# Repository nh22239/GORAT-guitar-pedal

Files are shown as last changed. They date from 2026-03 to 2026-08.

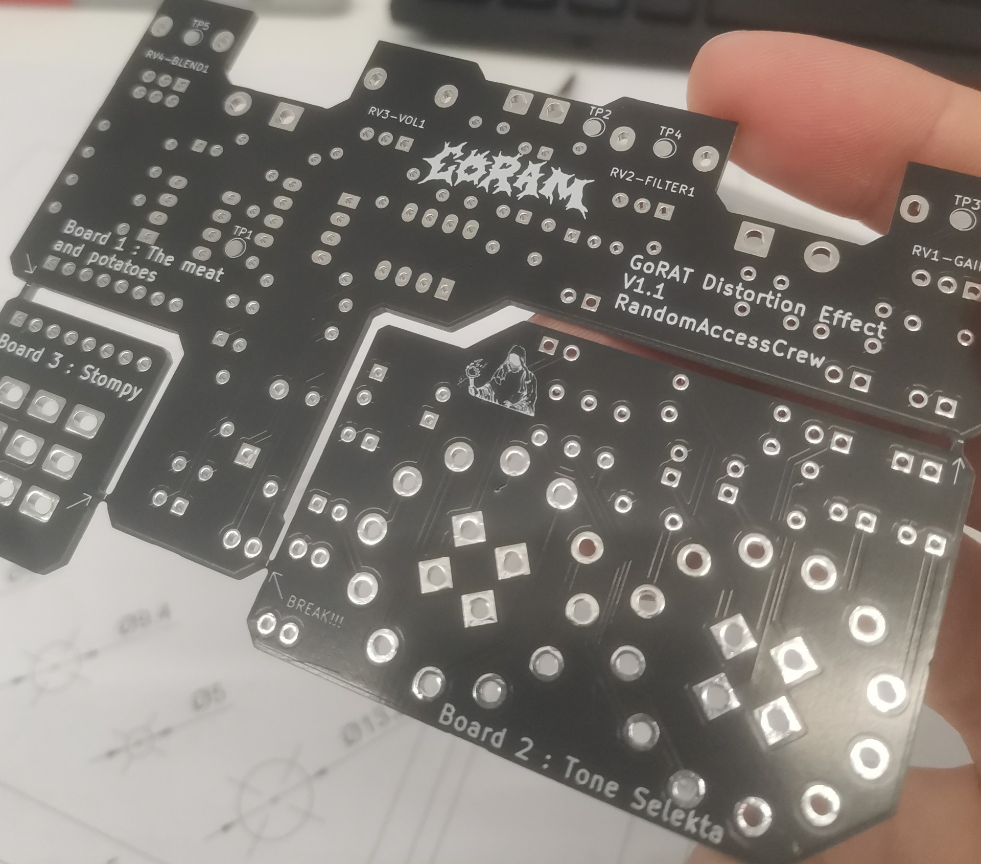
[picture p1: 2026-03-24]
PCBv1.1 delivery.jpg

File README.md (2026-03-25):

goram

# GORAT RAT clone 
Here at **GORAM** industries, we love the sound of a good dirty **RAT**, but what if we all want to use one at the same time? Suffice to say, we'd probably all get lost in eachothers sound.
That's why we've decided to go custom, a brand new **RAT** clone built by **GORAM**, for **GORAM**.

## New features:
### Frequency response selector switch!

  A simple knob that allows switching the filters of the op-amp stage between **Regular**, **Bass**, and **BEANS** modes
  
### Diode selector switch

  Pick between 6 different diode combinations
  1. BAT41 - BAT 41
  2. Red LED - Red LED 
  3. 1N914 - 1N914
  4. 1N914 - Open
  5. BAT41 - 1N914
  6. BAT41 - Red LED

### Wet/Dry knob
  Does what it says on the tin, for when the un-adulterated bass tone needs to shine through a bit more.

## Future Features:
### Diode selector gain compensation
  When switching diodes, also switch feedback resistor on a compensation op-amp.
### SMD components
  The enclosure is very busy, any new features would probably require this.
### Mini versions
  Much smaller package sizes individualised for Bass, Standard, and Beans.
### Colour LED display
  Switch between red, green, and blue when the feedback capacitor selector is changed, easy to implement as the 4x3 rotarty switch has a free pole but version 1.1 has run out of board space.

## Update 24/03/2026
The PCB's have arrived!
Due to the different heights of components, not to mention mechanical strain, I've designed the board to be printed as one piece that snaps off into three. The intention is that the breakout for the stomp button, and having flying wires for all of the jacks, will reduce the wear on the piece and contribute to a more professional finish.

PCBv1 1 delivery

LineDrawing
<?xml version="1.0" encoding="UTF-8" standalone="no"?>
<!-- Created with Inkscape (http://www.inkscape.org/) -->

<svg
   width="210mm"
   height="297mm"
   viewBox="0 0 210 297"
   version="1.1"
   id="svg1"
   xml:space="preserve"
   inkscape:version="1.4.2 (ebf0e94, 2025-05-08)"
   sodipodi:docname="LineDrawing.svg"
   xmlns:inkscape="http://www.inkscape.org/namespaces/inkscape"
   xmlns:sodipodi="http://sodipodi.sourceforge.net/DTD/sodipodi-0.dtd"
   xmlns="http://www.w3.org/2000/svg"
   xmlns:svg="http://www.w3.org/2000/svg"><sodipodi:namedview
     id="namedview1"
     pagecolor="#ffffff"
     bordercolor="#000000"
     borderopacity="0.25"
     inkscape:showpageshadow="2"
     inkscape:pageopacity="0.0"
     inkscape:pagecheckerboard="0"
     inkscape:deskcolor="#d1d1d1"
     inkscape:document-units="mm"
     inkscape:zoom="0.68862935"
     inkscape:cx="238.15424"
     inkscape:cy="382.64416"
     inkscape:window-width="1920"
     inkscape:window-height="991"
     inkscape:window-x="3191"
     inkscape:window-y="435"
     inkscape:window-maximized="1"
     inkscape:current-layer="layer1" /><defs
     id="defs1"><rect
       x="546.73824"
       y="238.45997"
       width="66.79936"
       height="36.65103"
       id="rect40" /><marker
       id="DistanceX"
       orient="auto"
       refX="0.0"
       refY="0.0"
       style="overflow:visible"><path
         d="M 3,-3 L -3,3 M 0,-5 L  0,5"
         style="stroke:#000000; stroke-width:0.5"
         id="path1" /></marker><pattern
       id="Hatch"
       patternUnits="userSpaceOnUse"
       width="8"
       height="8"
       x="0"
       y="0"><path
         d="M8 4 l-4,4"
         stroke="#000000"
         stroke-width="0.25"
         linecap="square"
         id="path2" /><path
         d="M6 2 l-4,4"
         stroke="#000000"
         stroke-width="0.25"
         linecap="square"
         id="path3" /><path
         d="M4 0 l-4,4"
         stroke="#000000"
         stroke-width="0.25"
         linecap="square"
         id="path4" /></pattern><symbol
       id="*MODEL_SPACE" /><symbol
       id="*PAPER_SPACE" /><marker
       id="DistanceX-0"
       orient="auto"
       refX="0.0"
       refY="0.0"
       style="overflow:visible"><path
         d="M 3,-3 L -3,3 M 0,-5 L  0,5"
         style="stroke:#000000; stroke-width:0.5"
         id="path1-9" /></marker><pattern
       id="Hatch-4"
       patternUnits="userSpaceOnUse"
       width="8"
       height="8"
       x="0"
       y="0"><path
         d="M8 4 l-4,4"
         stroke="#000000"
         stroke-width="0.25"
         linecap="square"
         id="path2-8" /><path
         d="M6 2 l-4,4"
         stroke="#000000"
         stroke-width="0.25"
         linecap="square"
         id="path3-8" /><path
         d="M4 0 l-4,4"
         stroke="#000000"
         stroke-width="0.25"
         linecap="square"
         id="path4-2" /></pattern><symbol
       id="*MODEL_SPACE-4" /><symbol
       id="*PAPER_SPACE-5" /><marker
       id="DistanceX-1"
       orient="auto"
       refX="0.0"
       refY="0.0"
       style="overflow:visible"><path
         d="M 3,-3 L -3,3 M 0,-5 L  0,5"
         style="stroke:#000000; stroke-width:0.5"
         id="path1-4" /></marker><pattern
       id="Hatch-2"
       patternUnits="userSpaceOnUse"
       width="8"
       height="8"
       x="0"
       y="0"><path
         d="M8 4 l-4,4"
         stroke="#000000"
         stroke-width="0.25"
         linecap="square"
         id="path2-3" /><path
         d="M6 2 l-4,4"
         stroke="#000000"
         stroke-width="0.25"
         linecap="square"
         id="path3-2" /><path
         d="M4 0 l-4,4"
         stroke="#000000"
         stroke-width="0.25"
         linecap="square"
         id="path4-21" /></pattern><symbol
       id="*MODEL_SPACE-6" /><symbol
       id="*PAPER_SPACE-8" /></defs><g
     inkscape:label="Layer 1"
     inkscape:groupmode="layer"
     id="layer1"><g
       inkscape:label="0"
       id="g13"
       transform="matrix(0.26458333,0,0,-0.26458333,173.01219,290.36032)"><path
         d="m -353.42983,925.10662 a 17.007875,17.007875 0 0 0 -34.01575,0 17.007875,17.007875 0 0 0 34.01575,0 z"
         style="fill:none;stroke:#000000"
         id="path5" /><path
         d="m -211.98102,921.32712 a 26.173228,26.173228 0 0 0 -52.34645,0 26.173228,26.173228 0 0 0 52.34645,0 z"
         style="fill:none;stroke:#000000"
         id="path6" /><path
         d="m -88.862904,925.10662 a 17.007875,17.007875 0 0 0 -34.015746,0 17.007875,17.007875 0 0 0 34.015746,0 z"
         style="fill:none;stroke:#000000"
         id="path7" /><path
         d="M -450.75266,972.35072 H -25.555824 V 870.30342 H -450.75266 Z"
         style="fill:none;stroke:#000000"
         id="path8" /><path
         d="m -450.75266,870.30342 v -11.33855 h 425.196836 v 11.33855 z"
         style="fill:none;stroke:#000000"
         id="path9" /><path
         d="m -450.75266,870.30342 h -11.33859 v 102.0473 h 11.33859 z"
         style="fill:none;stroke:#000000"
         id="path10" /><path
         d="m -450.75266,858.96487 a 11.338583,11.338583 0 0 0 -11.33859,11.33855 h 11.33859 z"
         style="fill:none;stroke:#000000"
         id="path11" /><path
         d="m -25.555824,972.35072 h 11.33859 v -102.0473 h -11.33859 z"
         style="fill:none;stroke:#000000"
         id="path12" /><path
         d="m -25.555824,870.30342 v -11.33855 a 11.338583,11.338583 0 0 1 11.33859,11.33855 z"
         style="fill:none;stroke:#000000"
         id="path13" /></g><g
       inkscape:label="0"
       id="g22"
       transform="matrix(0.26458333,0,0,0.26458333,108.07374,-177.71021)"><path
         d="m 73.322835,1029.8731 a 13.6063,13.6063 0 0 0 -27.212599,0 13.6063,13.6063 0 0 0 27.212599,0 z"
         style="fill:none;stroke:#000000"
         id="path5-5" /><path
         d="m -30.614173,1216.586 a 17.76378,17.76378 0 0 0 -35.527559,0 17.76378,17.76378 0 0 0 35.527559,0 z"
         style="fill:none;stroke:#000000"
         id="path6-1" /><path
         d="m 49.020472,1238.692 a 9.448819,9.448819 0 0 0 -18.897637,0 9.448819,9.448819 0 0 0 18.897637,0 z"
         style="fill:none;stroke:#000000"
         id="path7-7" /><path
         d="m -46.299213,1029.8731 a 13.606299,13.606299 0 0 0 -27.212598,0 13.606299,13.606299 0 0 0 27.212598,0 z"
         style="fill:none;stroke:#000000"
         id="path8-1" /><path
         d="m 192.94488,1028.9283 a 13.6063,13.6063 0 0 0 -27.2126,0 13.6063,13.6063 0 0 0 27.2126,0 z"
         style="fill:none;stroke:#000000"
         id="path9-1" /><path
         d="m -133.36819,1216.586 a 17.76378,17.76378 0 0 0 -35.52756,0 17.76378,17.76378 0 0 0 35.52756,0 z"
         style="fill:none;stroke:#000000"
         id="path10-5" /><path
         d="m 172.40073,1236.0464 a 24.999155,24.999155 0 0 0 -49.99831,0 24.999155,24.999155 0 0 0 49.99831,0 z"
         style="fill:none;stroke:#000000"
         id="path11-2" /><path
         d="m -165.92126,1029.8731 a 13.6063,13.6063 0 0 0 -27.2126,0 13.6063,13.6063 0 0 0 27.2126,0 z"
         style="fill:none;stroke:#000000"
         id="path12-7" /><path
         d="M 212.59842,958.11024 H -212.59842 V 1286.9291 H 212.59842 Z"
         style="fill:none;stroke:#000000"
         id="path13-6" /><path
         d="m 212.59842,946.77165 v 11.33859 h -425.19684 v -11.33859 z"
         style="fill:none;stroke:#000000"
         id="path14" /><path
         d="m -212.59842,946.77165 v 11.33859 h -11.33859 a 11.338583,11.338583 0 0 1 11.33859,-11.33859 z"
         style="fill:none;stroke:#000000"
         id="path15" /><path
         d="m -223.93701,958.11024 h 11.33859 v 328.81886 h -11.33859 z"
         style="fill:none;stroke:#000000"
         id="path16" /><path
         d="m 212.59842,1286.9291 v 11.3386 h -425.19684 v -11.3386 z"
         style="fill:none;stroke:#000000"
         id="path17" /><path
         d="m -212.59842,1286.9291 v 11.3386 a 11.338583,11.338583 0 0 1 -11.33859,-11.3386 z"
         style="fill:none;stroke:#000000"
         id="path18" /><path
         d="m 212.59842,958.11024 h 11.33859 v 328.81886 h -11.33859 z"
         style="fill:none;stroke:#000000"
         id="path19" /><path
         d="m 212.59842,1298.2677 a 11.338583,11.338583 0 0 0 11.33859,-11.3386 h -11.33859 z"
         style="fill:none;stroke:#000000"
         id="path20" /><path
         style="fill:none;stroke:#000000"
         d="M 212.598,946.772 V 958.11"
         id="path21" /><path
         d="m 212.59842,958.11024 h 11.33859 a 11.338583,11.338583 0 0 0 -11.33859,-11.33859 z"
         style="fill:none;stroke:#000000"
         id="path22" /></g><g
       inkscape:label="0"
       id="g10"
       transform="matrix(0,-0.26458333,-0.26458333,0,308.48541,119.99916)"><path
         d="m -164.40945,1107.4016 h 328.8189 v -102.0473 h -328.8189 z"
         style="fill:none;stroke:#000000"
         id="path5-57" /><path
         d="m -164.40945,1005.3543 v -11.33855 h 328.8189 v 11.33855 z"
         style="fill:none;stroke:#000000"
         id="path6-6" /><path
         d="m -164.40945,994.01575 a 11.338583,11.338583 0 0 0 -11.33858,11.33855 h 11.33858 z"
         style="fill:none;stroke:#000000"
         id="path7-1" /><path
         d="m -175.74803,1107.4016 h 11.33858 v -102.0473 h -11.33858 z"
         style="fill:none;stroke:#000000"
         id="path8-8" /><path
         d="m 175.74803,1005.3543 a 11.338583,11.338583 0 0 0 -11.33858,-11.33855 v 11.33855 z"
         style="fill:none;stroke:#000000"
         id="path9-9" /><path
         d="m 164.40945,1107.4016 h 11.33858 v -102.0473 h -11.33858 z"
         style="fill:none;stroke:#000000"
         id="path10-2" /></g><g
       inkscape:label="0"
       id="g28"
       transform="matrix(0,0.26458333,0.26458333,0,-92.15514,118.58116)"><path
         d="m -164.40945,1107.4016 h 328.8189 v -102.0473 h -328.8189 z"
         style="fill:none;stroke:#000000"
         id="path23" /><path
         d="m -164.40945,1005.3543 v -11.33855 h 328.8189 v 11.33855 z"
         style="fill:none;stroke:#000000"
         id="path24" /><path
         d="m -164.40945,994.01575 a 11.338583,11.338583 0 0 0 -11.33858,11.33855 h 11.33858 z"
         style="fill:none;stroke:#000000"
         id="path25" /><path
         d="m -175.74803,1107.4016 h 11.33858 v -102.0473 h -11.33858 z"
         style="fill:none;stroke:#000000"
         id="path26" /><path
         d="m 175.74803,1005.3543 a 11.338583,11.338583 0 0 0 -11.33858,-11.33855 v 11.33855 z"
         style="fill:none;stroke:#000000"
         id="path27" /><path
         d="m 164.40945,1107.4016 h 11.33858 v -102.0473 h -11.33858 z"
         style="fill:none;stroke:#000000"
         id="path28" /></g><g
       id="g37"
       transform="translate(0,8.4527814)"><path
         d="M 51.82946,206.78981 H 164.32945 V 179.7898 H 51.82946 Z"
         style="fill:none;stroke:#000000;stroke-width:0.264583"
         id="path32" /><path
         d="m 51.82946,179.7898 v -2.99999 h 112.49999 v 2.99999 z"
         style="fill:none;stroke:#000000;stroke-width:0.264583"
         id="path33" /><path
         d="m 51.82946,179.7898 h -3.000002 v 27.00001 h 3.000002 z"
         style="fill:none;stroke:#000000;stroke-width:0.264583"
         id="path34" /><path
         d="m 51.82946,176.78981 a 3,3 0 0 0 -3.000002,2.99999 h 3.000002 z"
         style="fill:none;stroke:#000000;stroke-width:0.264583"
         id="path35" /><path
         d="m 164.32945,206.78981 h 3.00001 V 179.7898 h -3.00001 z"
         style="fill:none;stroke:#000000;stroke-width:0.264583"
         id="path36" /><path
         d="m 164.32945,179.7898 v -2.99999 a 3,3 0 0 1 3.00001,2.99999 z"
         style="fill:none;stroke:#000000;stroke-width:0.264583"
         id="path37" /></g><text
       xml:space="preserve"
       style="font-size:4.9389px;line-height:1;font-family:Typewriter-Serial;-inkscape-font-specification:'Typewriter-Serial, Normal';text-align:center;writing-mode:lr-tb;direction:ltr;text-anchor:middle;white-space:pre;inline-size:24.3507;fill:#000000;stroke-width:0.365001;stroke-linejoin:round;paint-order:markers stroke fill"
       x="51.823742"
       y="72.78978"
       id="text37"
       transform="translate(7.6071151,-2.7168268)"><tspan
         x="51.823742"
         y="72.78978"
         id="tspan2"><tspan
           style="stroke-width:0.365"
           id="tspan1">Gain</tspan></tspan></text><text
       xml:space="preserve"
       style="font-size:4.9389px;line-height:1;font-family:Typewriter-Serial;-inkscape-font-specification:'Typewriter-Serial, Normal';text-align:center;writing-mode:lr-tb;direction:ltr;text-anchor:middle;white-space:pre;inline-size:24.3507;fill:#000000;stroke-width:0.365001;stroke-linejoin:round;paint-order:markers stroke fill"
       x="51.823742"
       y="72.78978"
       id="text38"
       transform="translate(39.937354,-2.9885095)"><tspan
         x="51.823742"
         y="72.78978"
         id="tspan4"><tspan
           style="stroke-width:0.365"
           id="tspan3">Filter</tspan></tspan></text><text
       xml:space="preserve"
       style="font-size:4.9389px;line-height:1;font-family:Typewriter-Serial;-inkscape-font-specification:'Typewriter-Serial, Normal';text-align:center;writing-mode:lr-tb;direction:ltr;text-anchor:middle;white-space:pre;inline-size:24.3507;fill:#000000;stroke-width:0.365001;stroke-linejoin:round;paint-order:markers stroke fill"
       x="51.823742"
       y="72.78978"
       id="text39"
       transform="translate(71.251067,-3.3727268)"><tspan
         x="51.823742"
         y="72.78978"
         id="tspan6"><tspan
           style="stroke-width:0.365"
           id="tspan5">Volume</tspan></tspan></text><text
       xml:space="preserve"
       transform="scale(0.26458333)"
       id="text40"
       style="text-orientation:auto;stroke-linejoin:round;-inkscape-font-specification:'Typewriter-Serial, Normal';font-family:Typewriter-Serial;font-size:18.66666667px;fill:#000000;line-height:1;paint-order:markers stroke fill;stroke-width:1.37952756;text-align:center;writing-mode:lr-tb;direction:ltr;white-space:pre;shape-inside:url(#rect40)" /><text
       xml:space="preserve"
       style="font-size:4.9389px;line-height:1;font-family:Typewriter-Serial;-inkscape-font-specification:'Typewriter-Serial, Normal';text-align:center;writing-mode:lr-tb;direction:ltr;text-anchor:middle;white-space:pre;inline-size:24.3507;fill:#000000;stroke-width:0.365001;stroke-linejoin:round;paint-order:markers stroke fill"
       x="51.823742"
       y="72.78978"
       id="text41"
       transform="translate(102.37267,-3.3727268)"><tspan
         x="51.823742"
         y="72.78978"
         id="tspan8"><tspan
           style="stroke-width:0.365"
           id="tspan7">Wet/Dry</tspan></tspan></text><text
       xml:space="preserve"
       style="font-size:4.9389px;line-height:1;font-family:Typewriter-Serial;-inkscape-font-specification:'Typewriter-Serial, Normal';text-align:center;writing-mode:lr-tb;direction:ltr;text-anchor:middle;white-space:pre;inline-size:24.3507;fill:#000000;stroke-width:0.365001;stroke-linejoin:round;paint-order:markers stroke fill"
       x="51.823742"
       y="72.78978"
       id="text42"
       transform="translate(14.194792,99.213302)"><tspan
         x="51.823742"
         y="72.78978"
         id="tspan10"><tspan
           style="stroke-width:0.365"
           id="tspan9">Bass/</tspan></tspan><tspan
         x="51.823742"
         y="77.728687"
         id="tspan12"><tspan
           style="stroke-width:0.365"
           id="tspan11">Reg/</tspan></tspan><tspan
         x="51.823742"
         y="82.667591"
         id="tspan14"><tspan
           style="stroke-width:0.365"
           id="tspan13">Beans</tspan></tspan></text><text
       xml:space="preserve"
       style="font-size:4.9389px;line-height:1;font-family:Typewriter-Serial;-inkscape-font-specification:'Typewriter-Serial, Normal';text-align:center;writing-mode:lr-tb;direction:ltr;text-anchor:middle;white-space:pre;inline-size:24.3507;fill:#000000;stroke-width:0.365001;stroke-linejoin:round;paint-order:markers stroke fill"
       x="51.823742"
       y="72.78978"
       id="text43"
       transform="translate(43.011092,99.789628)"><tspan
         x="51.823742"
         y="72.78978"
         id="tspan16"><tspan
           style="stroke-width:0.365"
           id="tspan15">Diode</tspan><tspan
           y="72.78978"
           id="tspan17"> </tspan></tspan><tspan
         x="51.823742"
         y="77.728687"
         id="tspan19"><tspan
           style="stroke-width:0.365"
           id="tspan18">Selection</tspan></tspan></text><text
       xml:space="preserve"
       style="font-size:4.9389px;line-height:1;font-family:Typewriter-Serial;-inkscape-font-specification:'Typewriter-Serial, Normal';text-align:center;writing-mode:lr-tb;direction:ltr;text-anchor:middle;white-space:pre;inline-size:24.3507;fill:#000000;stroke-width:0.365001;stroke-linejoin:round;paint-order:markers stroke fill"
       x="51.823742"
       y="72.78978"
       id="text44"
       transform="translate(70.866849,99.789628)"><tspan
         x="51.823742"
         y="72.78978"
         id="tspan21"><tspan
           style="stroke-width:0.365"
           id="tspan20">LED</tspan></tspan></text><text
       xml:space="preserve"
       style="font-size:4.9389px;line-height:1;font-family:Typewriter-Serial;-inkscape-font-specification:'Typewriter-Serial, Normal';text-align:center;writing-mode:lr-tb;direction:ltr;text-anchor:middle;white-space:pre;inline-size:34.7246;fill:#000000;stroke-width:0.365001;stroke-linejoin:round;paint-order:markers stroke fill"
       x="51.823742"
       y="72.78978"
       id="text45"
       transform="translate(95.26465,102.47915)"><tspan
         x="51.823742"
         y="72.78978"
         id="tspan23"><tspan
           style="stroke-width:0.365"
           id="tspan22">Footswitch</tspan></tspan></text><text
       xml:space="preserve"
       style="font-size:4.9389px;line-height:1;font-family:Typewriter-Serial;-inkscape-font-specification:'Typewriter-Serial, Normal';text-align:center;writing-mode:lr-tb;direction:ltr;text-anchor:middle;white-space:pre;inline-size:34.7246;fill:#000000;stroke-width:0.365001;stroke-linejoin:round;paint-order:markers stroke fill"
       x="51.823742"
       y="72.78978"
       id="text46"
       transform="translate(96.108218,-44.483981)"><tspan
         x="51.823742"
         y="72.78978"
         id="tspan25"><tspan
           style="stroke-width:0.365"
           id="tspan24">In</tspan></tspan></text><text
       xml:space="preserve"
       style="font-size:4.9389px;line-height:1;font-family:Typewriter-Serial;-inkscape-font-specification:'Typewriter-Serial, Normal';text-align:center;writing-mode:lr-tb;direction:ltr;text-anchor:middle;white-space:pre;inline-size:34.7246;fill:#000000;stroke-width:0.365001;stroke-linejoin:round;paint-order:markers stroke fill"
       x="51.823742"
       y="72.78978"
       id="text47"
       transform="translate(22.914816,-46.02085)"><tspan
         x="51.823742"
         y="72.78978"
         id="tspan27"><tspan
           style="stroke-width:0.365"
           id="tspan26">Out</tspan></tspan></text></g></svg>

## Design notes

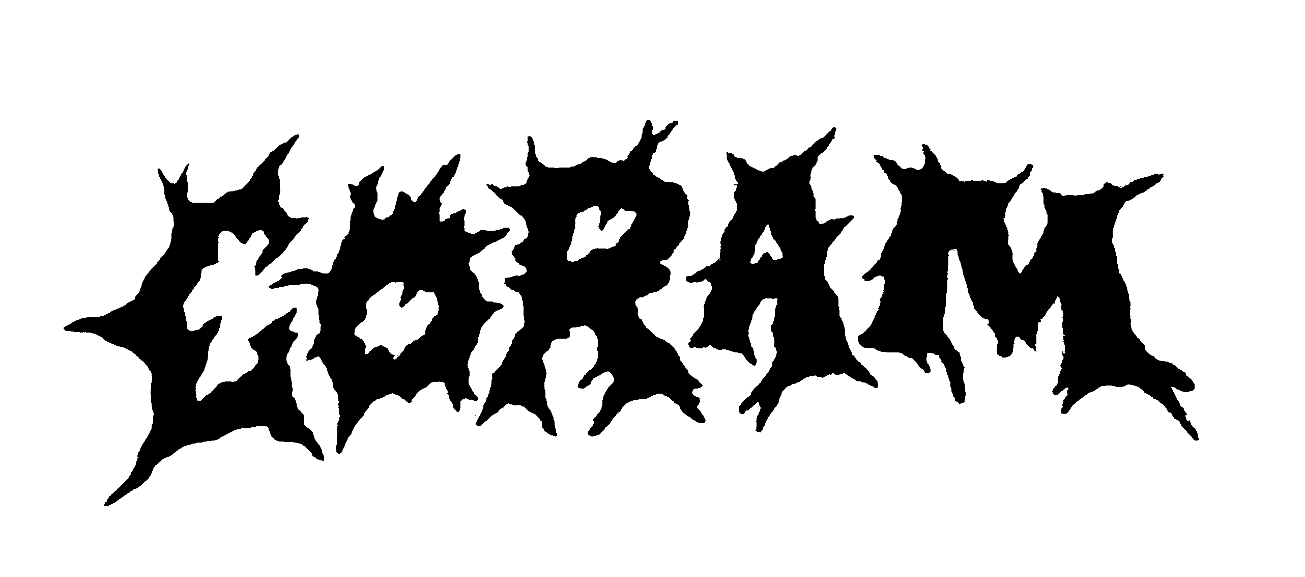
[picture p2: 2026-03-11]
goram.png

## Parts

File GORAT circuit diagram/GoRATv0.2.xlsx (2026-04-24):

Reference | Value | Manu No | Qty | Per batch | In Stock? | DNP | Exclude from BOM | Exclude from Board | Footprint | Supplier | Order code | Datasheet | Unit price | Subtotal
C1,C9 | 22n | K223K15X7RF5UH5 | 2 | 10 |  |  |  |  | Capacitor_THT:C_Disc_D4.7mm_W2.5mm_P5.00mm | cpc | CA10734 | ~ | £0.08
C2 | 1n | K102J15C0GF53L2 | 1 | 5 |  |  |  |  | Capacitor_THT:C_Disc_D4.7mm_W2.5mm_P5.00mm | cpc | CA06816 | ~ | £0.18
C3,C23,C24,C25,C26 | 10n | K103K15X7RH53L2 | 5 | 25 |  |  |  |  | Capacitor_THT:C_Disc_D4.7mm_W2.5mm_P5.00mm | cpc | CA06807 | ~ | £0.25
C4 | 100p | K101J15C0GF53L2 | 1 | 5 |  |  |  |  | Capacitor_THT:C_Disc_D4.7mm_W2.5mm_P5.00mm | cpc | CA06809 | ~ | £0.06
C5,C6,C18 | 1u | MCMLR50V105MY5V | 3 | 15 |  |  |  |  | Capacitor_THT:C_Disc_D4.7mm_W2.5mm_P5.00mm | cpc | CA08738 | ~ | £0.07
C8 | 68p | K680J15C0GF53L2 | 1 | 5 |  |  |  |  | Capacitor_THT:C_Disc_D4.7mm_W2.5mm_P5.00mm | cpc | CA06821 | ~ | £0.13
C12 | 0.1u | K104K15X7RF53L2 | 1 | 5 |  |  |  |  | Capacitor_THT:C_Disc_D4.7mm_W2.5mm_P5.00mm | cpc | CA06802 | ~ | £0.10
Cp7 | 4.7u | MCMHR63V475M5X7 | 1 | 5 |  |  |  |  | Capacitor_THT:CP_Radial_D5.0mm_P2.50mm | cpc | CA08251 | ~ | £0.05
Cp11 | 100u | 25YXJ100M5X11 | 1 | 5 |  |  |  |  | Capacitor_THT:CP_Radial_D5.0mm_P2.50mm | cpc | CA09737 | ~ | £0.09
Cp13 | 47u | ECA1CAK470X | 1 | 5 |  |  |  |  | Capacitor_THT:CP_Radial_D5.0mm_P2.50mm | cpc | CA05723 | ~ | £0.12
Cp14 | 10u | MCGPR25V106M5X11 | 1 | 5 |  |  |  |  | Capacitor_THT:CP_Radial_D5.0mm_P2.50mm | cpc | CA04744 | ~ | £0.23
Cp15 | 22u | MCGPR25V226M5X11 | 1 | 5 |  |  |  |  | Capacitor_THT:CP_Radial_D5.0mm_P2.50mm | cpc | CA04745 | ~ | £0.24
Cp19 | 1u | MCGPR50V105M5X11 | 1 | 5 |  |  |  |  | Capacitor_THT:CP_Radial_D5.0mm_P2.50mm | cpc | CA04763 | ~ | £0.21
D1,D2 | 1N914 | 1N914 | 2 | 10 |  |  |  |  | PCM_Diode_THT_AKL:D_DO-35_SOD27_P7.62mm_Horizontal | cpc | SC08157 | https://datasheet.octopart.com/1N914ATR-ON-Semiconductor-datasheet-42765246.pdf | £0.04
D3 | 1N4002 | 1N4002G | 1 | 5 |  |  |  |  | PCM_Diode_THT_AKL:D_DO-41_SOD81_P7.62mm_Horizontal | cpc | SC17771 | https://www.tme.eu/Document/5f8ffc5ac30fc86bac97d66040bf5502/1n400x.pdf | £0.06
D4 | Red | MP006838 | 1 | 5 |  |  |  |  | PCM_LED_THT_AKL:LED_D5.0mm | cpc | SC19413 |  | £0.06
D5,D6 | Red | HLMP-K150 | 2 | 10 |  |  |  |  | PCM_LED_THT_AKL:LED_D3.0mm | cpc | SC11548 |  | £0.24
D7,D8 | BAT41 | BAT41 | 2 | 10 |  |  |  |  | Diode_THT:D_DO-35_SOD27_P7.62mm_Horizontal | cpc | SC07323 | http://www.vishay.com/docs/85659/bat41.pdf | £0.26
J1,J2 | AudioJack2 | NYS229 | 2 | 10 |  |  |  |  | Off-board wiring | cpc | CN26775 | ~ | £0.75
J6 | Barrel_Jack | PPW01004 | 1 | 3 |  |  |  |  | Off-board wiring | cpc | AV15144 | ~ | £0.71
Q1 | J111 | J111 | 1 | 10 |  |  |  |  | PCM_Package_TO_SOT_THT_AKL:TO-92_Inline_Wide_DSG | cpc | SC12586 | https://www.tme.eu/Document/2ab8d7a6d6d8a209f9d7deeb52763e9f/J111.pdf | £0.21
R1,R2,R8,R14,R19,R23,R25 | 1M | MF50 1M | 7 | 1 |  |  |  |  | Resistor_THT:R_Axial_DIN0207_L6.3mm_D2.5mm_P10.16mm_Horizontal | cpc | RE05070 | ~ | £1.65
R3,R6 | 1K | MF50 1K | 2 | 1 |  |  |  |  | Resistor_THT:R_Axial_DIN0207_L6.3mm_D2.5mm_P10.16mm_Horizontal | cpc | RE05058 | ~ | £1.84
R4,R10 | 47ohm | MCF 1W 47R | 2 | 10 |  |  |  |  | Resistor_THT:R_Axial_DIN0207_L6.3mm_D2.5mm_P10.16mm_Horizontal | cpc | RE04043 | ~ | £0.13
R5 | 560ohm | MF50 560R | 1 | 1 |  |  |  |  | Resistor_THT:R_Axial_DIN0207_L6.3mm_D2.5mm_P10.16mm_Horizontal | cpc | RE05027 | ~ | £1.65
R7,R9, R11,R12,R15,R20,R22,R24 | 10k | MF50 10K | 8 | 1 |  |  |  |  | Resistor_THT:R_Axial_DIN0207_L6.3mm_D2.5mm_P10.16mm_Horizontal | cpc | RE05044 | ~ | £2.03
R13 | 2.2k | MF50 2K2 | 1 | 1 |  |  |  |  | Resistor_THT:R_Axial_DIN0207_L6.3mm_D2.5mm_P10.16mm_Horizontal | cpc | RE05035 | ~ | £2.38
R16,R17,R18 | 22k | MF50 22K | 3 | 1 |  |  |  |  | Resistor_THT:R_Axial_DIN0207_L6.3mm_D2.5mm_P10.16mm_Horizontal | cpc | RE05048 | ~ | £1.77
R21 | 27k | MF50 27K | 1 | 1 |  |  |  |  | Resistor_THT:R_Axial_DIN0207_L6.3mm_D2.5mm_P10.16mm_Horizontal | cpc | RE05049 | ~ | £1.65
R26,R27 | 47k | MF50 47K | 2 | 1 |  |  |  |  | Resistor_THT:R_Axial_DIN0207_L6.3mm_D2.5mm_P10.16mm_Horizontal | cpc | RE05052 | ~ | £1.73
RV1-GAIN1,RV3-VOLWet1,RV4-VOLDry1 | 100K | B100K - T18 shaft - Alpha Vertical 9mm Potentiometer | 3 | 15 |  |  |  |  | Daves customs:Potentiometer_Alpha_RD901F-40-00D_Single_Vertical | Thonk |  | ~ | £1.67
RV2-TILT1 | 100K | B100K - DUAL GANG - T18 shaft - Alpha Vertical 9mm Potentiometer | 1 | 5 |  |  |  |  | Potentiometer_THT:Potentiometer_Alpha_RD902F-40-00D_Dual_Vertical | Thonk |  | ~ | £1.99
S1 | SWITCH-3PDT |  | 1 | 5 |  |  |  |  | Daves customs:3PDT_fixed | pedalparts |  |  | £2.50
SW1 | SW_DPDT_x2 | 1MD1T6B11M1QE | 1 | 5 |  |  |  |  | Daves customs:DPDT_fixed | cpc | SW02868 | ~ | £1.86
SW8 | SW_Rotary2x6 | CK1050 | 1 | 5 |  |  |  |  | Daves customs:RS26 | cpc | SW02748 | http://cdn-reichelt.de/documents/datenblatt/C200/DS-Serie%23LOR.pdf | £2.55
 | Knob (pot) | Tall Synthpointer - Large - T18 Shaft | 4 | 20 |  |  |  |  |  |  |  |  | £0.91
 | Knob (rot) | Black - Medium (6.35mm Round Shaft) - Synth Pointer Plastic Knob | 1 | 5 |  |  |  |  |  |  |  |  | £1.65
U1 | OP07CP | OP07CP | 1 | 5 |  |  |  |  | PCM_Package_DIP_AKL:DIP-8_W7.62mm_LongPads | cpc | SC16157 | http://web.mit.edu/6.301/www/LM108.pdf | £1.98
U2,U3 | TL072ACP | TL072ACP | 2 | 10 |  |  |  |  | PCM_Package_DIP_AKL:DIP-8_W7.62mm_LongPads | cpc | SC16455 | https://www.ti.com/lit/ds/symlink/tl072h.pdf?ts=1635057479364 | £1.38
Enclosure | 1590BB | 1590BB | 1 | 5 |  |  |  |  |  | cpc | EN82042

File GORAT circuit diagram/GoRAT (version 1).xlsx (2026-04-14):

Reference | Value | Manufacturer No | Qty | per batch | DNP | Exclude from BOM | Exclude from Board | Footprint | Supplier | Order code | Datasheet | Unit Price (inc VAT) | Subtotal | Batch price
C1,C9 | 22n | K223K15X7RF5UH5 | 2 | 10 |  |  |  | Capacitor_THT:C_Disc_D4.7mm_W2.5mm_P5.00mm | CPC | CA10734 | ~ | £0.08 | £0.16 | £0.80
C2 | 1n | K102J15C0GF53L2 | 1 | 5 |  |  |  | Capacitor_THT:C_Disc_D4.7mm_W2.5mm_P5.00mm | CPC | CA06816 | ~ | £0.10 | £0.10 | £0.50
C4 | 100p | K101J15C0GF53L2 | 1 | 5 |  |  |  | Capacitor_THT:C_Disc_D4.7mm_W2.5mm_P5.00mm | CPC | CA06809 | ~ | £0.06 | £0.06 | £0.30
C5 | 2.2u | 50ML2R2MEFC4X5 | 1 | 5 |  |  |  | Capacitor_THT:CP_Radial_D5.0mm_P2.50mm | CPC | CA07533 | ~ | £0.26 | £0.26 | £1.30
C6,C7 | 4.7u | 50MS54R7M0557 | 2 | 10 |  |  |  | Capacitor_THT:CP_Radial_D5.0mm_P2.50mm | CPC | CA05565 | ~ | £0.18 | £0.36 | £1.80
C8 | 3.3n | MCRR50332X7RK0100 | 1 | 5 |  |  |  | Capacitor_THT:C_Disc_D4.7mm_W2.5mm_P5.00mm | CPC | CA06300 | ~ | £0.16 | £0.16 | £0.80
C10,C13,C19 | 1u | MCGPR50V105M5X11 | 3 | 1 |  |  |  | Capacitor_THT:CP_Radial_D5.0mm_P2.50mm | CPC | CA04763 | ~ | £0.25 | £0.75 | £0.25
C11 | 100u | 25YXJ100M5X11 | 1 | 5 |  |  |  | Capacitor_THT:CP_Radial_D5.0mm_P2.50mm | CPC | CA09737 | ~ | £0.11 | £0.11 | £0.55
C12 | 0.1u | K104K15X7RF53L2 | 1 | 5 |  |  |  | Capacitor_THT:C_Disc_D4.7mm_W2.5mm_P5.00mm | CPC | CA06802 | ~ | £0.12 | £0.12 | £0.60
C14 | 10u | MCGPR25V106M5X11 | 1 | 1 |  |  |  | Capacitor_THT:CP_Radial_D5.0mm_P2.50mm | CPC | CA04744 | ~ | £0.28 | £0.28 | £0.28
C15 | 22u | MCGPR25V226M5X11 | 1 | 1 |  |  |  | Capacitor_THT:CP_Radial_D5.0mm_P2.50mm | CPC | CA04745 | ~ | £0.29 | £0.29 | £0.29
C16 | 68p | K680J15C0GF53L2 | 1 | 5 |  |  |  | Capacitor_THT:C_Disc_D4.7mm_W2.5mm_P5.00mm | CPC | CA06821 | ~ | £0.16 | £0.16 | £0.80
C17 | 47p | K470J15C0GF53L2 | 1 | 5 |  |  |  | Capacitor_THT:C_Disc_D4.7mm_W2.5mm_P5.00mm | CPC | CA06814 | ~ | £0.17 | £0.17 | £0.85
C18, C21 | 470n | MCRR50474Z5UM0050 | 2 | 10 |  |  |  | Capacitor_THT:C_Disc_D4.7mm_W2.5mm_P5.00mm | CPC | CA05523 | ~ | £0.50 | £1.00 | £5.00
C20 | 220n | K224K20X7RF53L2 | 1 | 5 |  |  |  | Capacitor_THT:C_Disc_D4.7mm_W2.5mm_P5.00mm | CPC | CA06812 | ~ | £0.42 | £0.42 | £2.10
C22 | 33p | K330J15C0GF53L2 | 1 | 5 |  |  |  | Capacitor_THT:C_Disc_D4.7mm_W2.5mm_P5.00mm | CPC | CA06806 | ~ | £0.38 | £0.38 | £1.90
D1,D2 | 1N914 | 1N914 | 2 | 10 |  |  |  | PCM_Diode_THT_AKL:D_DO-35_SOD27_P7.62mm_Horizontal | CPC | SC08157 | https://datasheet.octopart.com/1N914ATR-ON-Semiconductor-datasheet-42765246.pdf | £0.04 | £0.08 | £0.40
D3 | 1N4002 | 1N4002G | 1 | 5 |  |  |  | PCM_Diode_THT_AKL:D_DO-41_SOD81_P7.62mm_Horizontal | CPC | SC17771 | https://www.tme.eu/Document/5f8ffc5ac30fc86bac97d66040bf5502/1n400x.pdf | £0.06 | £0.06 | £0.30
D4,D5,D6 | Red | MP006838 | 3 | 15 |  |  |  | PCM_SparkFun-LED:LED_5mm_PTH_Red_NoSilk | CPC | SC19413 | https://cdn.sparkfun.com/assets/e/c/e/c/5/COM-09590-YSL-R531R3D-D2.pdf | £0.07 | £0.21 | £1.05
D7,D8 | BAT41 | BAT41 | 2 | 10 |  |  |  | Diode_THT:D_DO-35_SOD27_P7.62mm_Horizontal | CPC | SC07323 | http://www.vishay.com/docs/85659/bat41.pdf | £0.26 | £0.52 | £2.60
J1,J2 | AudioJack2 | NYS229 | 2 | 10 |  |  |  | Off-board wiring | CPC | CN26775 | ~ | £0.75 | £1.50 | £7.50
J6 | Barrel_Jack | PPW01004 | 1 | 3 |  |  |  | Off-board wiring | CPC | AV15144 | ~ | £0.71 | £0.71 | £2.13
Q1 | J111 | J111 | 1 | 5 |  |  |  | PCM_Package_TO_SOT_THT_AKL:TO-92_Inline_Wide_DSG | CPC | SC12586 | https://www.tme.eu/Document/2ab8d7a6d6d8a209f9d7deeb52763e9f/J111.pdf | £0.25 | £0.25 | £1.25
R1,R2,R8,R14,R18 | 1M | MF12 1M | 5 | 1 |  |  |  | Resistor_THT:R_Axial_DIN0207_L6.3mm_D2.5mm_P10.16mm_Horizontal | CPC | RE04070 | ~ | £0.03 | £0.14 | £0.03
R3,R6 | 1K | MF50 1K | 2 | 1 |  |  |  | Resistor_THT:R_Axial_DIN0207_L6.3mm_D2.5mm_P10.16mm_Horizontal | CPC | RE05031 | ~ | £0.05 | £0.10 | £0.05
R4,R10 | 47 | MF50 47R | 2 | 1 |  |  |  | Resistor_THT:R_Axial_DIN0207_L6.3mm_D2.5mm_P10.16mm_Horizontal | CPC | RE05013 | ~ | £0.04 | £0.08 | £0.04
R5 | 560 | MF50 560R | 1 | 1 |  |  |  | Resistor_THT:R_Axial_DIN0207_L6.3mm_D2.5mm_P10.16mm_Horizontal | CPC | RE05027 | ~ | £0.04 | £0.04 | £0.04
R7 | 1.5K | MCF 0.5W 1K5 | 1 | 1 |  |  |  | Resistor_THT:R_Axial_DIN0207_L6.3mm_D2.5mm_P10.16mm_Horizontal | CPC | RE04479 | ~ | £0.03 | £0.03 | £0.03
R9 | 10K | MF50 10K | 1 | 1 |  |  |  | Resistor_THT:R_Axial_DIN0207_L6.3mm_D2.5mm_P10.16mm_Horizontal | CPC | RE05044 | ~ | £0.02 | £0.02 | £0.02
R11,R12 | 100K | MF50 100K | 2 | 1 |  |  |  | Resistor_THT:R_Axial_DIN0207_L6.3mm_D2.5mm_P10.16mm_Horizontal | CPC | RE05057 | ~ | £0.06 | £0.11 | £0.06
R13 | 2.2k | MF50 2K2 | 1 | 1 |  |  |  | Resistor_THT:R_Axial_DIN0207_L6.3mm_D2.5mm_P10.16mm_Horizontal | CPC | RE05035 | ~ | £0.06 | £0.06 | £0.06
R15,R16,R17 | 22k | MF50 22K | 3 | 1 |  |  |  | Resistor_THT:R_Axial_DIN0207_L6.3mm_D2.5mm_P10.16mm_Horizontal | CPC | RE05048 | ~ | £0.04 | £0.13 | £0.04
RV1-GAIN1,RV2-FILTER1 | B100K | RD901F-40-15K-B100K | 2 | 10 |  |  |  | Daves customs:Potentiometer_Alpha_RD901F-40-00D_Single_Vertical | Thonk |  | ~ | £2.00 | £4.00 | £20.00
RV3-VOL1 | A100K | RD901F-40-15K-A100K | 1 | 5 |  |  |  |  | Thonk |  |  | £2.00 | £2.00 | £10.00
RV4-BLEND1 | B100K | RD902F-40-15K-B100K | 1 | 5 |  |  |  | Potentiometer_THT:Potentiometer_Alpha_RD902F-40-00D_Dual_Vertical | Thonk |  | ~ | £2.00 | £2.00 | £10.00
S1 | SWITCH-3PDT |  | 1 | 5 |  |  |  | Daves customs:3PDT | Ebay |  |  | £1.03 | £1.03 | £5.13
SW3 | SW_Rotary4x3 | CK1052 | 1 | 5 |  |  |  | Daves customs:RS26 | CPC | SW02750 | http://cdn-reichelt.de/documents/datenblatt/C200/DS-Serie%23LOR.pdf | £3.06 | £3.06 | £15.30
SW8 | SW_Rotary2x6 | CK1050 | 1 | 5 |  |  |  | Daves customs:RS26 | CPC | SW02748 | http://cdn-reichelt.de/documents/datenblatt/C200/DS-Serie%23LOR.pdf | £2.98 | £2.98 | £14.90
U1 | OP07CP | OP07CP | 1 | 5 |  |  |  | PCM_Package_DIP_AKL:DIP-8_W7.62mm_LongPads | CPC | SC16157 | http://web.mit.edu/6.301/www/LM108.pdf | £2.38 | £2.38 | £11.90
U2,U3 | TL072ACP | TL072CP | 2 | 10 |  |  |  | PCM_Package_DIP_AKL:DIP-8_W7.62mm_LongPads | CPC | SC17220 | https://www.ti.com/lit/ds/symlink/tl072h.pdf?ts=1635057479364 | £1.20 | £2.40 | £12.00
Yellow Enclosure | 1590 | 1590BBYL | 1 | 5 |  |  |  | No footprint | CPC | EN84638 | IP54 Die Cast Aluminium Instrument Enclosure - 119x94x30mm - Hammond | CPC | £12.79 | £12.79 | £63.95
PCB |  |  | 1 | 5 |  |  |  |  | JLC PCB |  |  | £5.18 | £5.18 | £25.89
 |  |  |  |  |  |  |  |  |  |  |  | Total | £46.63 | £222.79

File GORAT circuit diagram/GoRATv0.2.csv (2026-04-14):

Reference | Qty | Value | DNP | Exclude from BOM | Exclude from Board | Footprint | Datasheet
C1,C9 | 2 | 22n |  |  |  | Capacitor_THT:C_Disc_D4.7mm_W2.5mm_P5.00mm | ~
C2 | 1 | 1n |  |  |  | Capacitor_THT:C_Disc_D4.7mm_W2.5mm_P5.00mm | ~
C3,C23,C24,C25,C26 | 5 | 10n |  |  |  | Capacitor_THT:C_Disc_D4.7mm_W2.5mm_P5.00mm | ~
C4 | 1 | 100p |  |  |  | Capacitor_THT:C_Disc_D4.7mm_W2.5mm_P5.00mm | ~
C5,C6,C18 | 3 | 1u |  |  |  | Capacitor_THT:C_Disc_D4.7mm_W2.5mm_P5.00mm | ~
C8 | 1 | 68p |  |  |  | Capacitor_THT:C_Disc_D4.7mm_W2.5mm_P5.00mm | ~
C12 | 1 | 0.1u |  |  |  | Capacitor_THT:C_Disc_D4.7mm_W2.5mm_P5.00mm | ~
Cp7 | 1 | 4.7u |  |  |  | Capacitor_THT:CP_Radial_D5.0mm_P2.50mm | ~
Cp11 | 1 | 100u |  |  |  | Capacitor_THT:CP_Radial_D5.0mm_P2.50mm | ~
Cp13 | 1 | 47u |  |  |  | Capacitor_THT:CP_Radial_D5.0mm_P2.50mm | ~
Cp14 | 1 | 10u |  |  |  | Capacitor_THT:CP_Radial_D5.0mm_P2.50mm | ~
Cp15 | 1 | 22u |  |  |  | Capacitor_THT:CP_Radial_D5.0mm_P2.50mm | ~
Cp19 | 1 | 1u |  |  |  | Capacitor_THT:CP_Radial_D5.0mm_P2.50mm | ~
D1,D2 | 2 | 1N914 |  |  |  | PCM_Diode_THT_AKL:D_DO-35_SOD27_P7.62mm_Horizontal | https://datasheet.octopart.com/1N914ATR-ON-Semiconductor-datasheet-42765246.pdf
D3 | 1 | 1N4002 |  |  |  | PCM_Diode_THT_AKL:D_DO-41_SOD81_P7.62mm_Horizontal | https://www.tme.eu/Document/5f8ffc5ac30fc86bac97d66040bf5502/1n400x.pdf
D4 | 1 | Red |  |  |  | PCM_LED_THT_AKL:LED_D5.0mm | https://cdn.sparkfun.com/assets/e/c/e/c/5/COM-09590-YSL-R531R3D-D2.pdf
D5,D6 | 2 | Red |  |  |  | PCM_LED_THT_AKL:LED_D3.0mm | https://cdn.sparkfun.com/assets/e/c/e/c/5/COM-09590-YSL-R531R3D-D2.pdf
D7,D8 | 2 | BAT41 |  |  |  | Diode_THT:D_DO-35_SOD27_P7.62mm_Horizontal | http://www.vishay.com/docs/85659/bat41.pdf
J1,J2 | 2 | AudioJack2 |  |  |  | Connector_Wire:SolderWire-0.75sqmm_1x02_P7mm_D1.25mm_OD3.5mm | ~
J3,J4 | 2 | Conn_01x08_Socket |  |  |  | Connector_PinHeader_2.54mm:PinHeader_1x08_P2.54mm_Vertical | ~
J6 | 1 | Barrel_Jack |  |  |  | Connector_Wire:SolderWire-0.5sqmm_1x02_P4.6mm_D0.9mm_OD2.1mm | ~
J8,J9,SP1,SP2 | 4 | Conn_01x02_Socket |  |  |  | Connector_PinHeader_2.54mm:PinHeader_1x02_P2.54mm_Vertical | ~
Q1 | 1 | J111 |  |  |  | PCM_Package_TO_SOT_THT_AKL:TO-92_Inline_Wide_DSG | https://www.tme.eu/Document/2ab8d7a6d6d8a209f9d7deeb52763e9f/J111.pdf
R1,R2,R8,R14,R19,R23,R25 | 7 | 1M |  |  |  | Resistor_THT:R_Axial_DIN0207_L6.3mm_D2.5mm_P10.16mm_Horizontal | ~
R3,R6 | 2 | 1K |  |  |  | Resistor_THT:R_Axial_DIN0207_L6.3mm_D2.5mm_P10.16mm_Horizontal | ~
R4,R10 | 2 | 47 |  |  |  | Resistor_THT:R_Axial_DIN0207_L6.3mm_D2.5mm_P10.16mm_Horizontal | ~
R5 | 1 | 560 |  |  |  | Resistor_THT:R_Axial_DIN0207_L6.3mm_D2.5mm_P10.16mm_Horizontal | ~
R7,R11,R12,R15,R20,R22,R24 | 7 | 10k |  |  |  | Resistor_THT:R_Axial_DIN0207_L6.3mm_D2.5mm_P10.16mm_Horizontal | ~
R9 | 1 | 10K |  |  |  | Resistor_THT:R_Axial_DIN0207_L6.3mm_D2.5mm_P10.16mm_Horizontal | ~
R13 | 1 | 2.2k |  |  |  | Resistor_THT:R_Axial_DIN0207_L6.3mm_D2.5mm_P10.16mm_Horizontal | ~
R16,R17,R18 | 3 | 22k |  |  |  | Resistor_THT:R_Axial_DIN0207_L6.3mm_D2.5mm_P10.16mm_Horizontal | ~
R21 | 1 | 27k |  |  |  | Resistor_THT:R_Axial_DIN0207_L6.3mm_D2.5mm_P10.16mm_Horizontal | ~
R26,R27 | 2 | 47k |  |  |  | Resistor_THT:R_Axial_DIN0207_L6.3mm_D2.5mm_P10.16mm_Horizontal | ~
RV1-GAIN1,RV3-VOLWet1,RV4-VOLDry1 | 3 | 100K |  |  |  | Daves customs:Potentiometer_Alpha_RD901F-40-00D_Single_Vertical | ~
RV2-TILT1 | 1 | 100K |  |  |  | Potentiometer_THT:Potentiometer_Alpha_RD902F-40-00D_Dual_Vertical | ~
S1 | 1 | SWITCH-3PDT |  |  |  | Daves customs:3PDT_fixed
SW1 | 1 | SW_DPDT_x2 |  |  |  | Daves customs:DPDT_fixed | ~
SW8 | 1 | SW_Rotary2x6 |  |  |  | Daves customs:RS26 | http://cdn-reichelt.de/documents/datenblatt/C200/DS-Serie%23LOR.pdf
TP2 | 1 | Pre-gain |  |  |  | TestPoint:TestPoint_Pad_D2.0mm | ~
TP3 | 1 | Post-gain |  |  |  | TestPoint:TestPoint_Pad_D2.0mm | ~
U1 | 1 | OP07CP |  |  |  | PCM_Package_DIP_AKL:DIP-8_W7.62mm_LongPads | http://web.mit.edu/6.301/www/LM108.pdf
U2,U3 | 2 | TL072ACP |  |  |  | PCM_Package_DIP_AKL:DIP-8_W7.62mm_LongPads | https://www.ti.com/lit/ds/symlink/tl072h.pdf?ts=1635057479364

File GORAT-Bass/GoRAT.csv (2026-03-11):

Reference | Qty | Value | DNP | Exclude from BOM | Exclude from Board | Footprint | Datasheet
C1,C9 | 2 | 22n |  |  |  | Capacitor_THT:C_Disc_D4.7mm_W2.5mm_P5.00mm | ~
C2 | 1 | 1n |  |  |  | Capacitor_THT:C_Disc_D4.7mm_W2.5mm_P5.00mm | ~
C4 | 1 | 100p |  |  |  | Capacitor_THT:C_Disc_D4.7mm_W2.5mm_P5.00mm | ~
C5 | 1 | 2.2u |  |  |  | Capacitor_THT:CP_Radial_D5.0mm_P2.50mm | ~
C6,C7 | 2 | 4.7u |  |  |  | Capacitor_THT:CP_Radial_D5.0mm_P2.50mm | ~
C8 | 1 | 3.3n |  |  |  | Capacitor_THT:C_Disc_D4.7mm_W2.5mm_P5.00mm | ~
C10,C13,C19 | 3 | 1u |  |  |  | Capacitor_THT:CP_Radial_D5.0mm_P2.50mm | ~
C11 | 1 | 100u |  |  |  | Capacitor_THT:CP_Radial_D5.0mm_P2.50mm | ~
C12 | 1 | 0.1u |  |  |  | Capacitor_THT:C_Disc_D4.7mm_W2.5mm_P5.00mm | ~
C14 | 1 | 10u |  |  |  | Capacitor_THT:CP_Radial_D5.0mm_P2.50mm | ~
C15 | 1 | 22u |  |  |  | Capacitor_THT:CP_Radial_D5.0mm_P2.50mm | ~
C16 | 1 | 68p |  |  |  | Capacitor_THT:C_Disc_D4.7mm_W2.5mm_P5.00mm | ~
C17 | 1 | 47p |  |  |  | Capacitor_THT:C_Disc_D4.7mm_W2.5mm_P5.00mm | ~
C18 | 1 | 470n |  |  |  | Capacitor_THT:C_Disc_D4.7mm_W2.5mm_P5.00mm | ~
C20 | 1 | 220n |  |  |  | Capacitor_THT:C_Disc_D5.1mm_W3.2mm_P5.00mm | ~
C21 | 1 | 470n |  |  |  | Capacitor_THT:C_Disc_D5.1mm_W3.2mm_P5.00mm | ~
C22 | 1 | 33p |  |  |  | Capacitor_THT:C_Disc_D4.7mm_W2.5mm_P5.00mm | ~
D1,D2 | 2 | 1N914 |  |  |  | PCM_Diode_THT_AKL:D_DO-35_SOD27_P7.62mm_Horizontal | https://datasheet.octopart.com/1N914ATR-ON-Semiconductor-datasheet-42765246.pdf
D3 | 1 | 1N4002 |  |  |  | PCM_Diode_THT_AKL:D_DO-41_SOD81_P7.62mm_Horizontal | https://www.tme.eu/Document/5f8ffc5ac30fc86bac97d66040bf5502/1n400x.pdf
D4,D5,D6 | 3 | Red |  |  |  | PCM_SparkFun-LED:LED_5mm_PTH_Red_NoSilk | https://cdn.sparkfun.com/assets/e/c/e/c/5/COM-09590-YSL-R531R3D-D2.pdf
D7,D8 | 2 | BAT41 |  |  |  | Diode_THT:D_DO-35_SOD27_P7.62mm_Horizontal | http://www.vishay.com/docs/85659/bat41.pdf
J1,J2 | 2 | AudioJack2 |  |  |  | Connector_Wire:SolderWire-0.75sqmm_1x02_P7mm_D1.25mm_OD3.5mm | ~
J3,J4 | 2 | Conn_01x08_Socket |  |  |  | Connector_PinHeader_2.54mm:PinHeader_1x08_P2.54mm_Vertical | ~
J5,J7,J8,J9,J10,J11 | 6 | Conn_01x02_Socket |  |  |  | Connector_PinHeader_2.54mm:PinHeader_1x02_P2.54mm_Vertical | ~
J6 | 1 | Barrel_Jack |  |  |  | Connector_Wire:SolderWire-0.5sqmm_1x02_P4.6mm_D0.9mm_OD2.1mm | ~
Q1 | 1 | J111 |  |  |  | PCM_Package_TO_SOT_THT_AKL:TO-92_Inline_Wide_DSG | https://www.tme.eu/Document/2ab8d7a6d6d8a209f9d7deeb52763e9f/J111.pdf
R1,R2,R8,R14,R18 | 5 | 1M |  |  |  | Resistor_THT:R_Axial_DIN0207_L6.3mm_D2.5mm_P10.16mm_Horizontal | ~
R3,R6 | 2 | 1K |  |  |  | Resistor_THT:R_Axial_DIN0207_L6.3mm_D2.5mm_P10.16mm_Horizontal | ~
R4,R10 | 2 | 47 |  |  |  | Resistor_THT:R_Axial_DIN0207_L6.3mm_D2.5mm_P10.16mm_Horizontal | ~
R5 | 1 | 560 |  |  |  | Resistor_THT:R_Axial_DIN0207_L6.3mm_D2.5mm_P10.16mm_Horizontal | ~
R7 | 1 | 1.5K |  |  |  | Resistor_THT:R_Axial_DIN0207_L6.3mm_D2.5mm_P10.16mm_Horizontal | ~
R9 | 1 | 10K |  |  |  | Resistor_THT:R_Axial_DIN0207_L6.3mm_D2.5mm_P10.16mm_Horizontal | ~
R11,R12 | 2 | 100K |  |  |  | Resistor_THT:R_Axial_DIN0207_L6.3mm_D2.5mm_P10.16mm_Horizontal | ~
R13 | 1 | 2.2k |  |  |  | Resistor_THT:R_Axial_DIN0207_L6.3mm_D2.5mm_P10.16mm_Horizontal | ~
R15,R16,R17 | 3 | 22k |  |  |  | Resistor_THT:R_Axial_DIN0207_L6.3mm_D2.5mm_P10.16mm_Horizontal | ~
RV1-GAIN1,RV2-FILTER1,RV3-VOL1 | 3 | 100K |  |  |  | Daves customs:Potentiometer_Alpha_RD901F-40-00D_Single_Vertical | ~
RV4-BLEND1 | 1 | 100K |  |  |  | Potentiometer_THT:Potentiometer_Alpha_RD902F-40-00D_Dual_Vertical | ~
S1 | 1 | SWITCH-3PDT |  |  |  | Daves customs:3PDT
SW3 | 1 | SW_Rotary4x3 |  |  |  | Daves customs:RS26 | http://cdn-reichelt.de/documents/datenblatt/C200/DS-Serie%23LOR.pdf
SW8 | 1 | SW_Rotary2x6 |  |  |  | Daves customs:RS26 | http://cdn-reichelt.de/documents/datenblatt/C200/DS-Serie%23LOR.pdf
U1 | 1 | OP07CP |  |  |  | PCM_Package_DIP_AKL:DIP-8_W7.62mm_LongPads | http://web.mit.edu/6.301/www/LM108.pdf
U2,U3 | 2 | TL072ACP |  |  |  | PCM_Package_DIP_AKL:DIP-8_W7.62mm_LongPads | https://www.ti.com/lit/ds/symlink/tl072h.pdf?ts=1635057479364

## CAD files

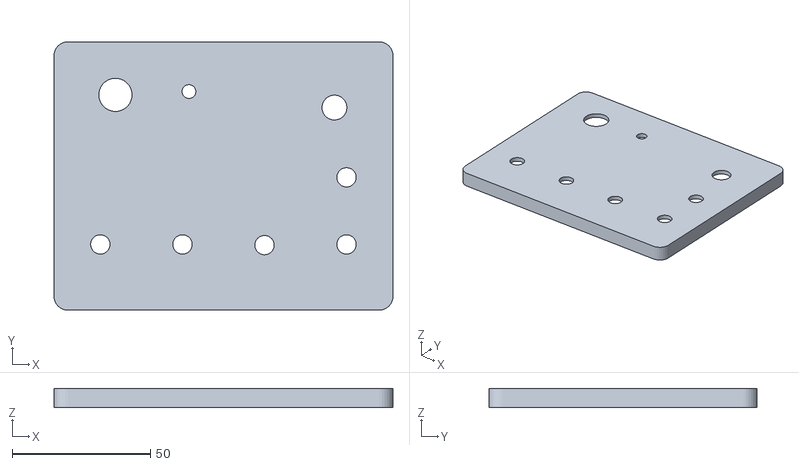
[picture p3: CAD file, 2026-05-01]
drill guide goratv0.2 top.stl
122.5 x 97.0 x 7.00

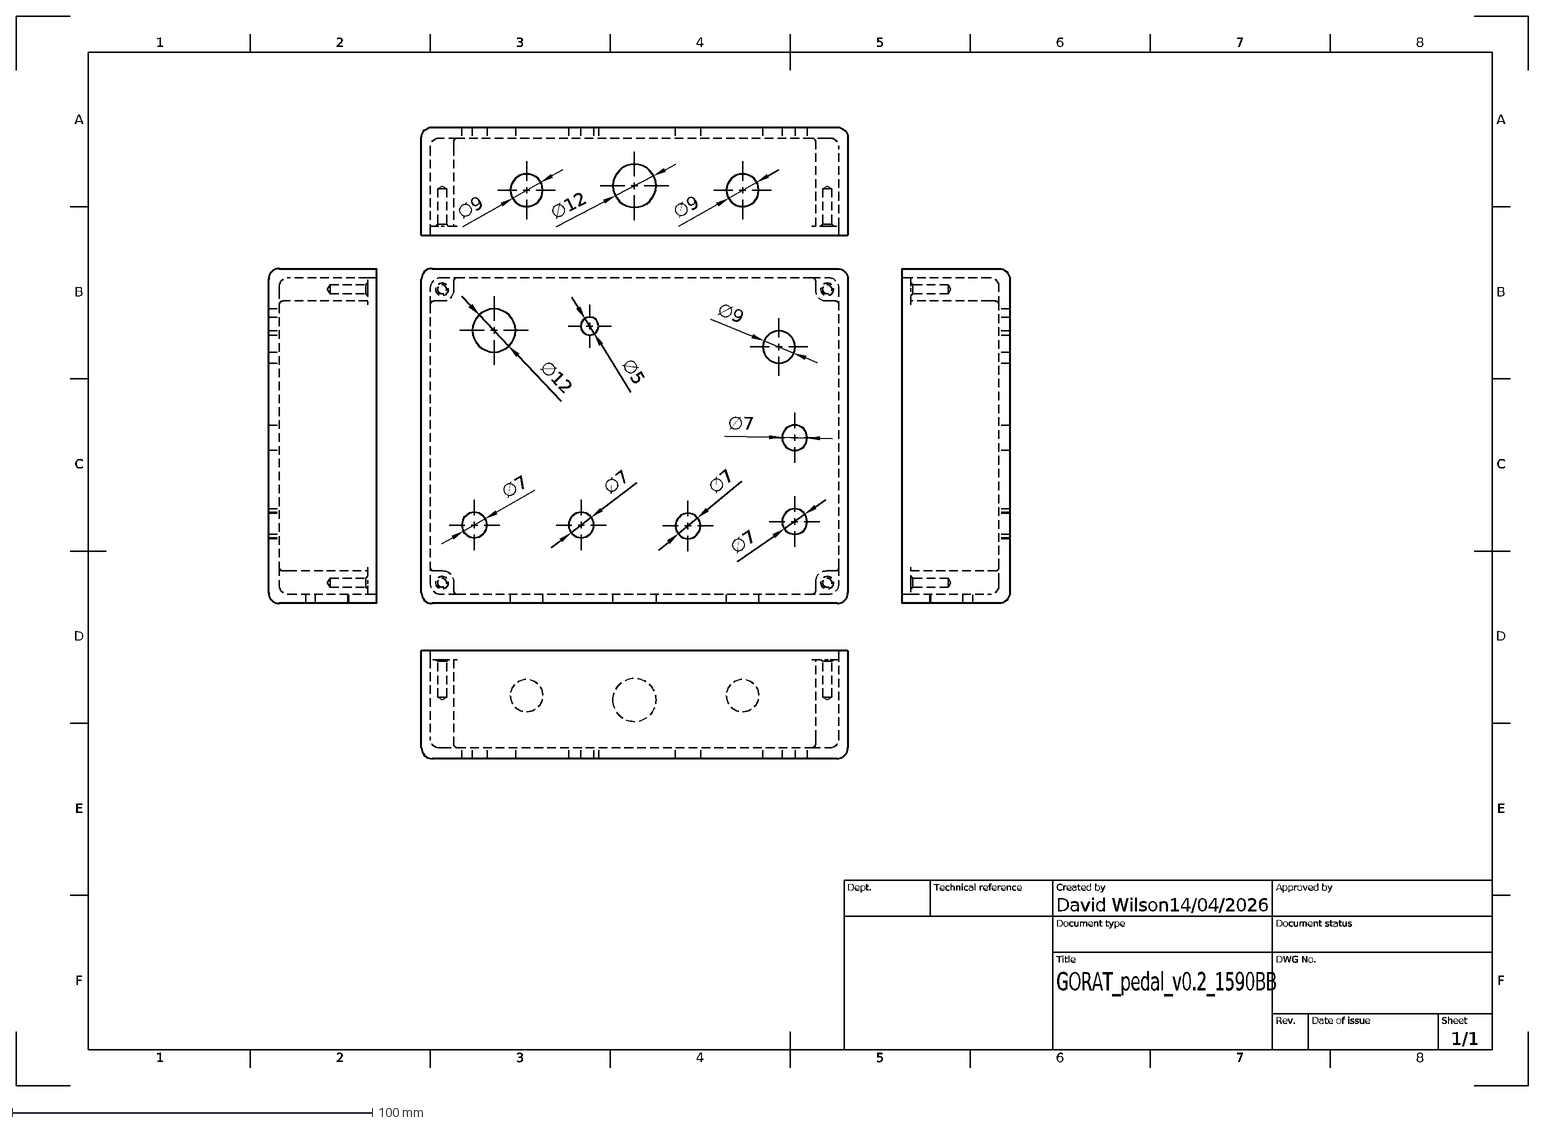
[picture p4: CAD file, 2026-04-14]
GORAT circuit diagram/GORAT_pedal_v0.2_1590BB Drawing v1 Sheet1.dxf
1
A
2
3
4
5
6
7
8
B
C
D
E
F
14/04/2026
1/1
GORAT_pedal_v0.2_1590BB
David Wilson
Dept.
Technical reference
Created by
Approved by
Document type
Document status
Title
DWG No.
Rev.
Date of issue
Sheet
∅12
∅5
∅9
∅7

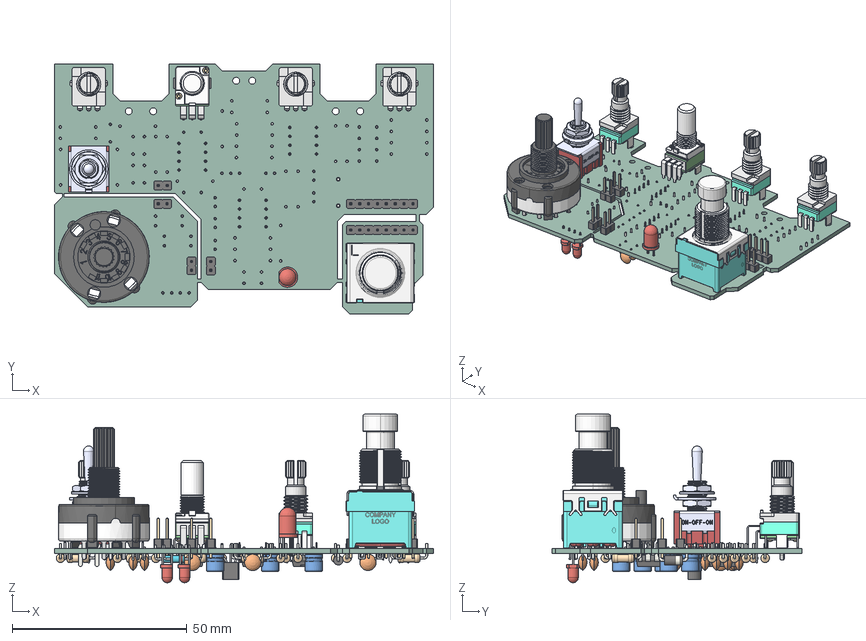
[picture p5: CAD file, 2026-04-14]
GORAT circuit diagram/GoRATv0.2.step
108.5 x 71.5 x 48.3 mm
PinHeader_1x08_P2.54mm_Vertical x 2
Vertical Potentiometer 15mm Axis x 3
LED_D5.0mm
RS26 Rotary Switch
PinHeader_1x02_P2.54mm_Vertical x 4
GÃRVA_MECHANO_3PDT_FOOTSWITCH
RD902F-40-00D
Washer Anti Twist Protection
Nut M6x0.75mm
Nut M6x0.75mm clone
Fantastic Plastic Body
Neck
Washer
PCB PIN 01
PCB PIN clone 02
PCB PIN clone 03
PCB PIN clone 04
PCB PIN clone 05
PCB PIN clone 06
Sheetmatal Frame
Font O 001
Font N 001
Font - 001
Font O 002
Font F 001
Font F 002
Font - 002
Font O 003
Font N 002
Batton
C_Disc_D4.7mm_W2.5mm_P5.00mm x 14
R_Axial_DIN0207_L6.3mm_D2.5mm_P10.16mm_Horizontal x 27
D_DO-35_SOD27_P7.62mm_Horizontal x 4
CP_Radial_D5.0mm_P2.50mm x 6
TO-92_Inline_Wide
DIP-8_W7.62mm x 3
D_DO-41_SOD81_P7.62mm_Horizontal
LED_D3.0mm x 2
GORAT circuit diagram_PCB

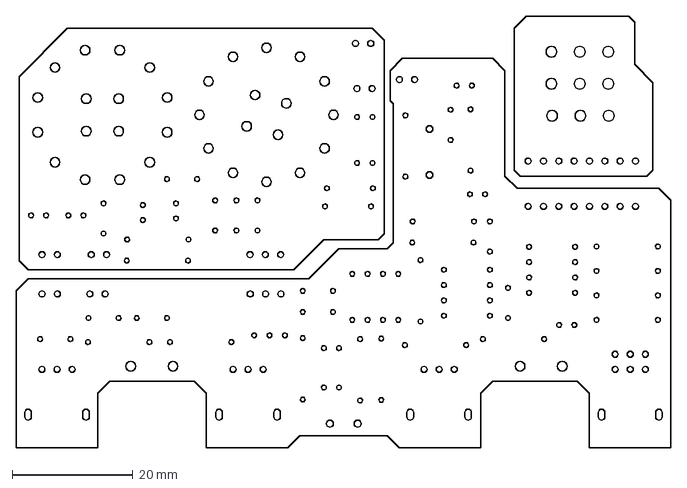
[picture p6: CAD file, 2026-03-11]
Underside-layout.dxf
108.5 x 71.5 mm

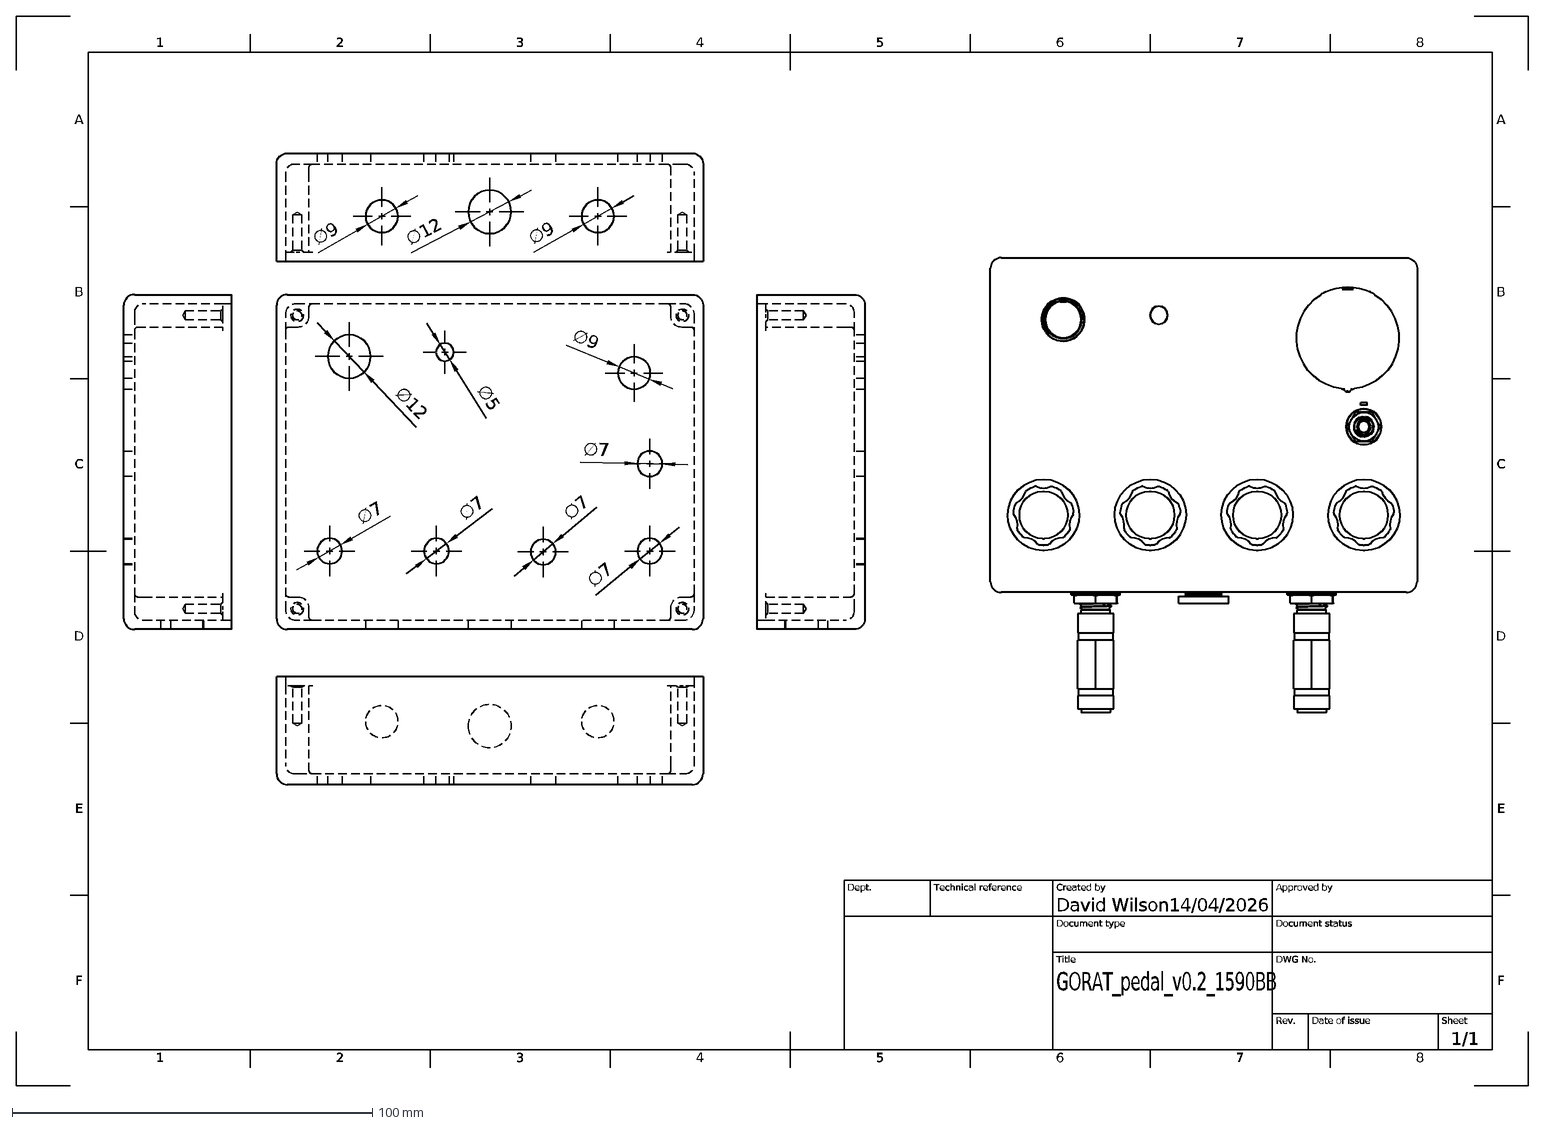
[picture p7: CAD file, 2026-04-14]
GORAT circuit diagram/GORAT_pedal_v0.2_1590BB Drawing v4 Sheet1.dxf
1
A
2
3
4
5
6
7
8
B
C
D
E
F
14/04/2026
1/1
GORAT_pedal_v0.2_1590BB
David Wilson
Dept.
Technical reference
Created by
Approved by
Document type
Document status
Title
DWG No.
Rev.
Date of issue
Sheet
∅12
∅5
∅9
∅7

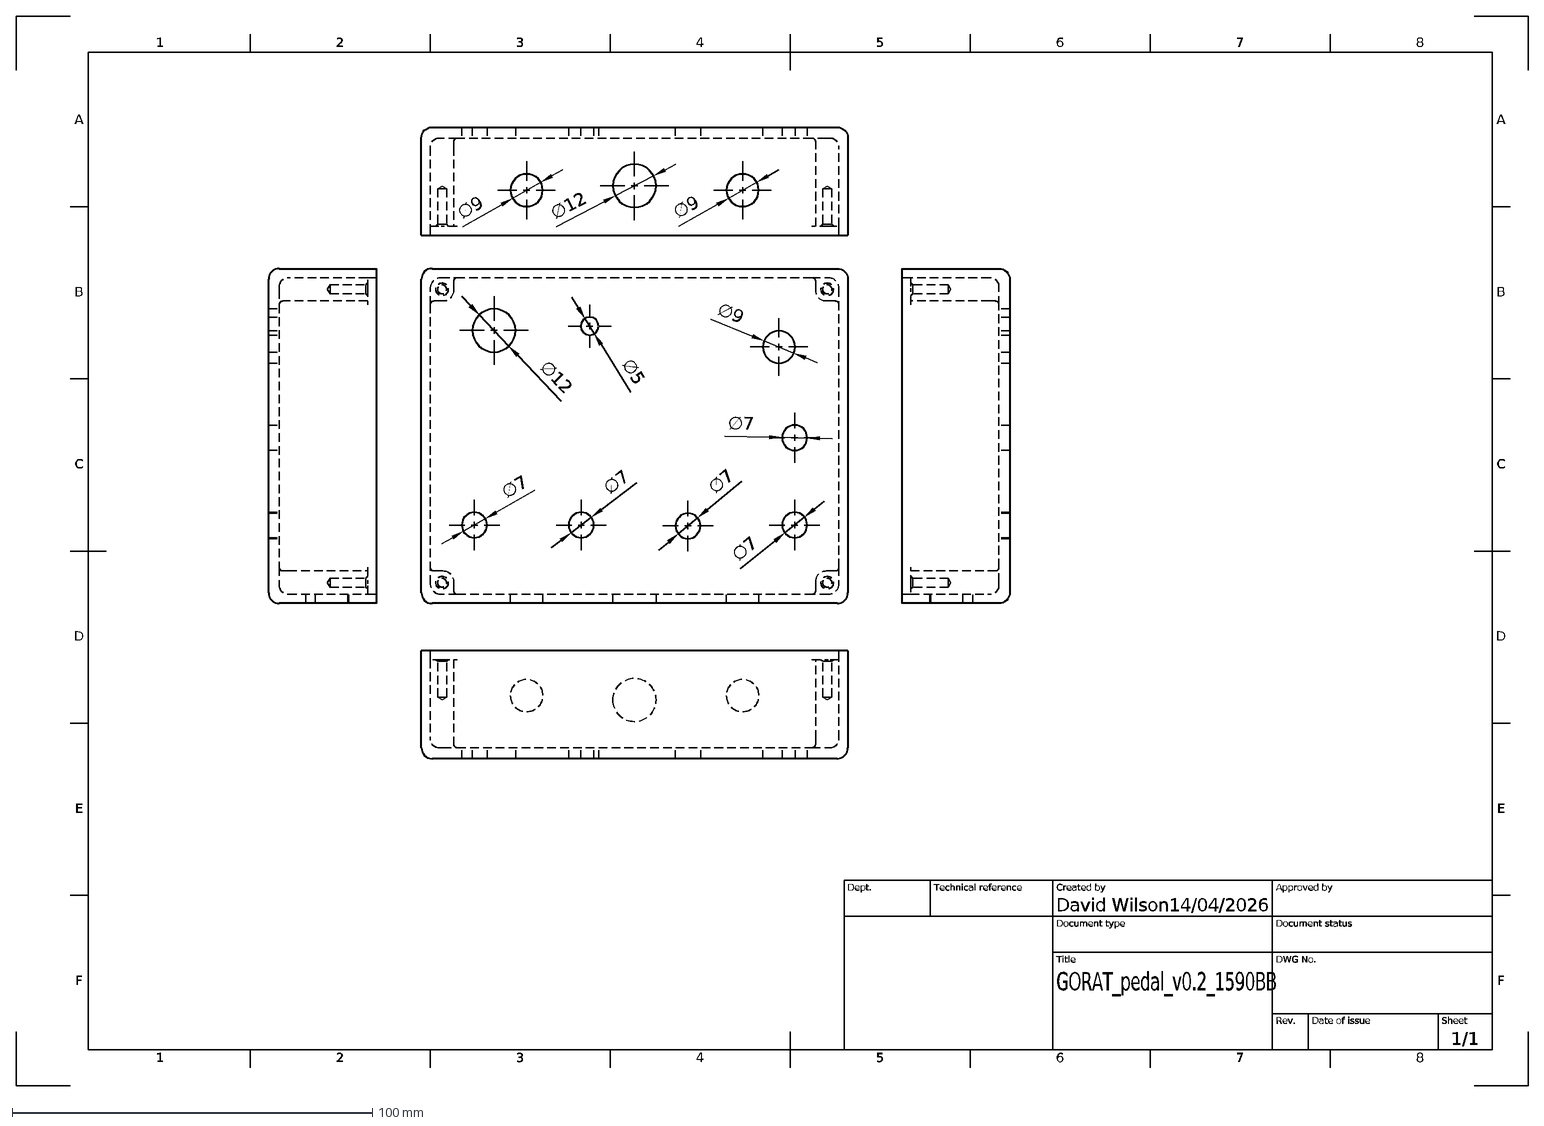
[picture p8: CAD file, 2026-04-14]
GORAT circuit diagram/GORAT_pedal_v0.2_1590BB Drawing v2 Sheet1.dxf
1
A
2
3
4
5
6
7
8
B
C
D
E
F
14/04/2026
1/1
GORAT_pedal_v0.2_1590BB
David Wilson
Dept.
Technical reference
Created by
Approved by
Document type
Document status
Title
DWG No.
Rev.
Date of issue
Sheet
∅12
∅5
∅9
∅7

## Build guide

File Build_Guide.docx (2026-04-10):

BOM

Reference | Value | Manufacturer No | Qty
C1,C9 | 22n | K223K15X7RF5UH5 | 2
C2 | 1n | K102J15C0GF53L2 | 1
C4 | 100p | K101J15C0GF53L2 | 1
C5 | 2.2u | 50ML2R2MEFC4X5 | 1
C6,C7 | 4.7u | 50MS54R7M0557 | 2
C8 | 3.3n | MCRR50332X7RK0100 | 1
C10,C13,C19 | 1u | MCGPR50V105M5X11 | 3
C11 | 100u | 25YXJ100M5X11 | 1
C12 | 0.1u | K104K15X7RF53L2 | 1
C14 | 10u | MCGPR25V106M5X11 | 1
C15 | 22u | MCGPR25V226M5X11 | 1
C16 | 68p | K680J15C0GF53L2 | 1
C17 | 47p | K470J15C0GF53L2 | 1
C18, C21 | 470n | MCRR50474Z5UM0050 | 2
C20 | 220n | K224K20X7RF53L2 | 1
C22 | 33p | K330J15C0GF53L2 | 1
D1,D2 | 1N914 | 1N914 | 2
D3 | 1N4002 | 1N4002G | 1
D4,D5,D6 | Red | MP006838 | 3
D7,D8 | BAT41 | BAT41 | 2
J1,J2 | AudioJack2 | NYS229 | 2
J6 | Barrel_Jack | PPW01004 | 1
Q1 | J111 | J111 | 1
R1,R2,R8,R14,R18 | 1M | MF12 1M | 5
R3,R6 | 1K | MF50 1K | 2
R4,R10 | 47Ω | MF50 47R | 2
R5 | 560Ω | MF50 560R | 1
R7 | 1.5K | MCF 0.5W 1K5 | 1
R9 | 10K | MF50 10K | 1
R11,R12 | 100K | MF50 100K | 2
R13 | 2.2k | MF50 2K2 | 1
R15,R16,R17 | 22k | MF50 22K | 3
RV1-GAIN1,RV2-FILTER1 | B100K | RD901F-40-15K-B100K | 2
RV3-VOL1 | A100K | RD901F-40-15K-A100K | 1
RV4-BLEND1 | B100K | RD902F-40-15K-B100K | 1
S1 | SWITCH-3PDT | | 1
SW3 | SW_Rotary4x3 | CK1052 | 1
SW8 | SW_Rotary2x6 | CK1050 | 1
U1 | OP07CP | OP07CP | 1
U2,U3 | TL072ACP | TL072CP | 2
Yellow Enclosure | 1590 | 1590BBYL | 1

Soldering guide

Break off the two sub-boards (2: tone selecta, 3: stompy) from the main board (1: the meat and potatoes). The break-points are labelled on the bottom side of the board.

With reference to the BOM, work through soldering each component. Start with low-profile components (resistors, diodes, capacitors) and work up to high-profile components (potentiometers, rotary switches).

Leave the connections between boards, and with the off-board components (audio and power jacks), they will be added last.

FIXES FOR VERSION 1.2:

- Connection from C1(1) and J3(4), and between C19(2) and J3(5), signal in and out of circuit.
- Test points more obvious?
- Rotary switch footprints (A,B,C,D, get placement correct, line up pin 1)
- Move most components to underside of board, should make for easier troubleshooting and less cramped.
- Better order of diode selection (not switching both diodes at once)
- Potentiometer directionality, Gain, Filter
- Wet/Dry functionality (buffer was in wrong configuration, input into -) Also check biasing of this section…
- Silkscreens, some components were missing
- Soft/hard clipping switch
- Replace 2x6 diode selection switch with 1x12 as the two poles are connected anyway and this could allow 12 different diode type pairings
- Active treble cut/boost instead of passive filter, OR implement tilt EQ (intense)

NOTE:

Any boards marked V1.1 have a grave error, the input and output pins for the entire effects circuit are disconnected.

This can be fixed by throwing a wire between C1(1) and J3(4), and between C19(2) and J3(5).

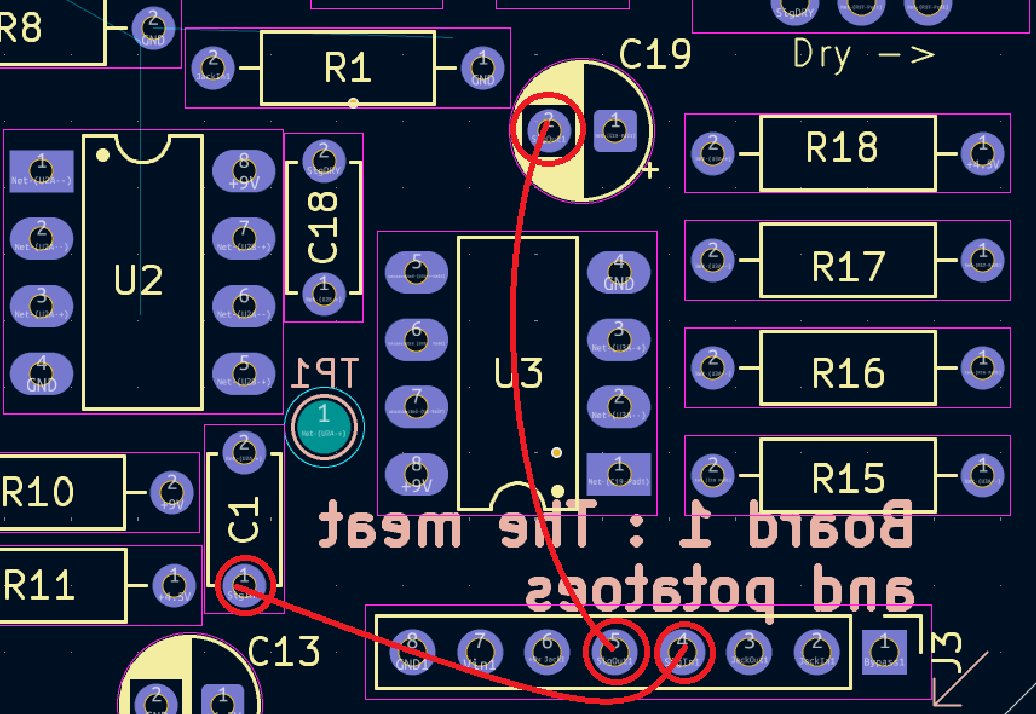
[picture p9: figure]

Enclosure guide

Top side

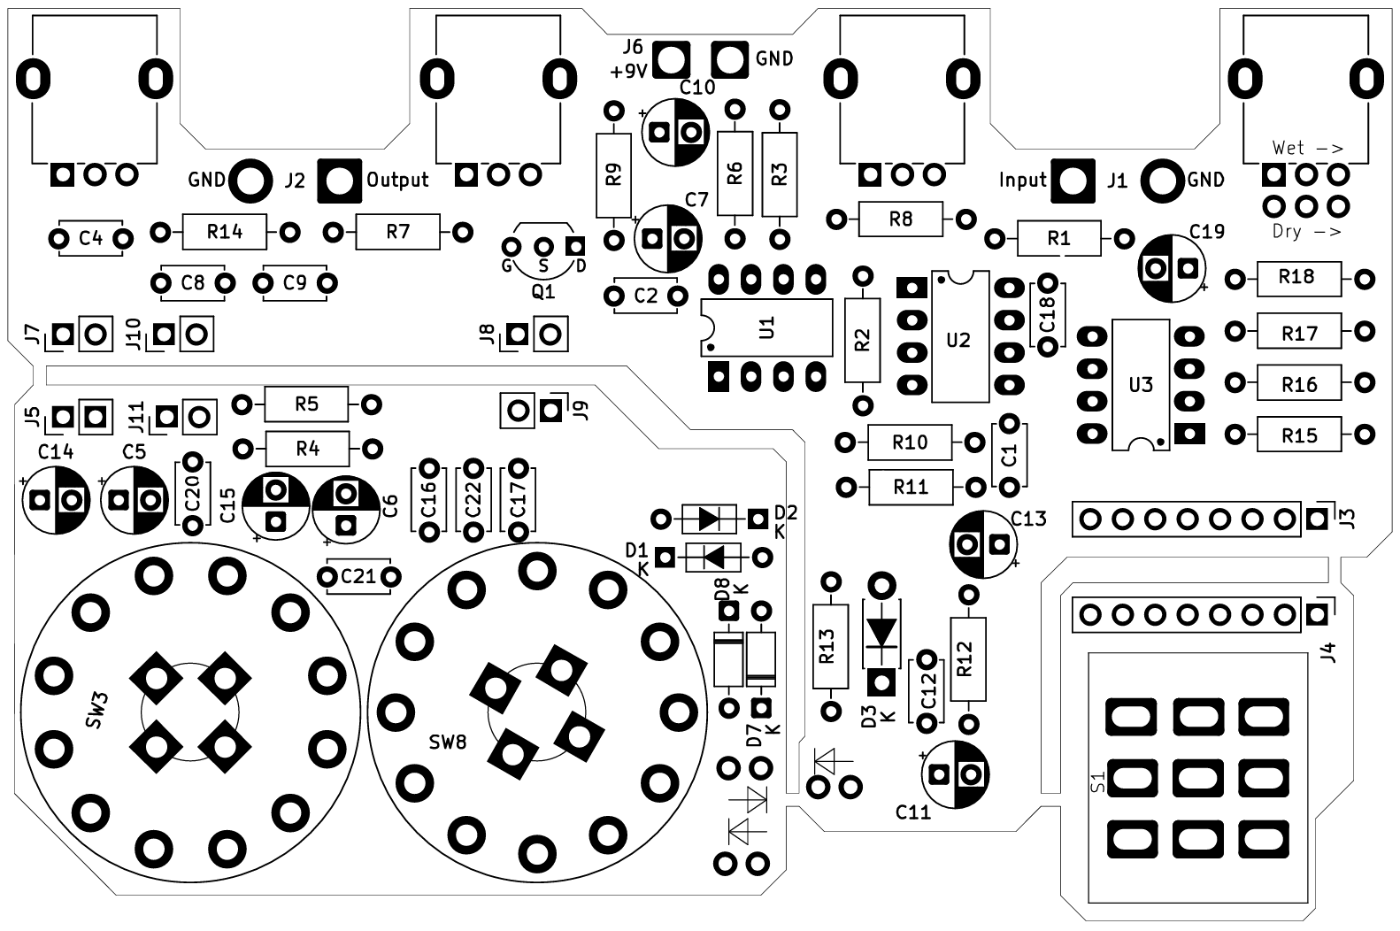
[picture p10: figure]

Bottom Side

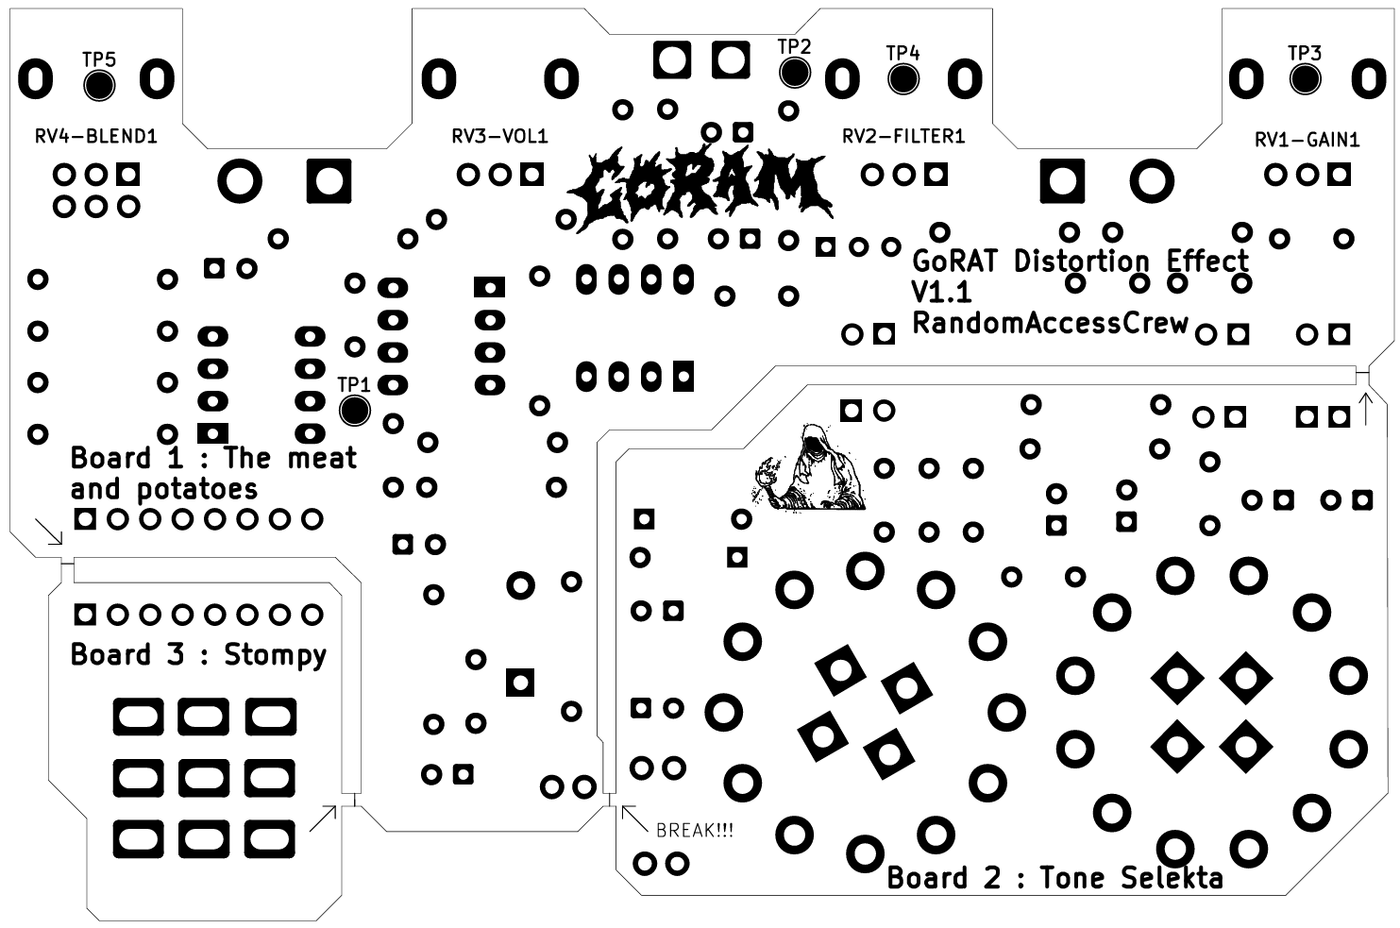
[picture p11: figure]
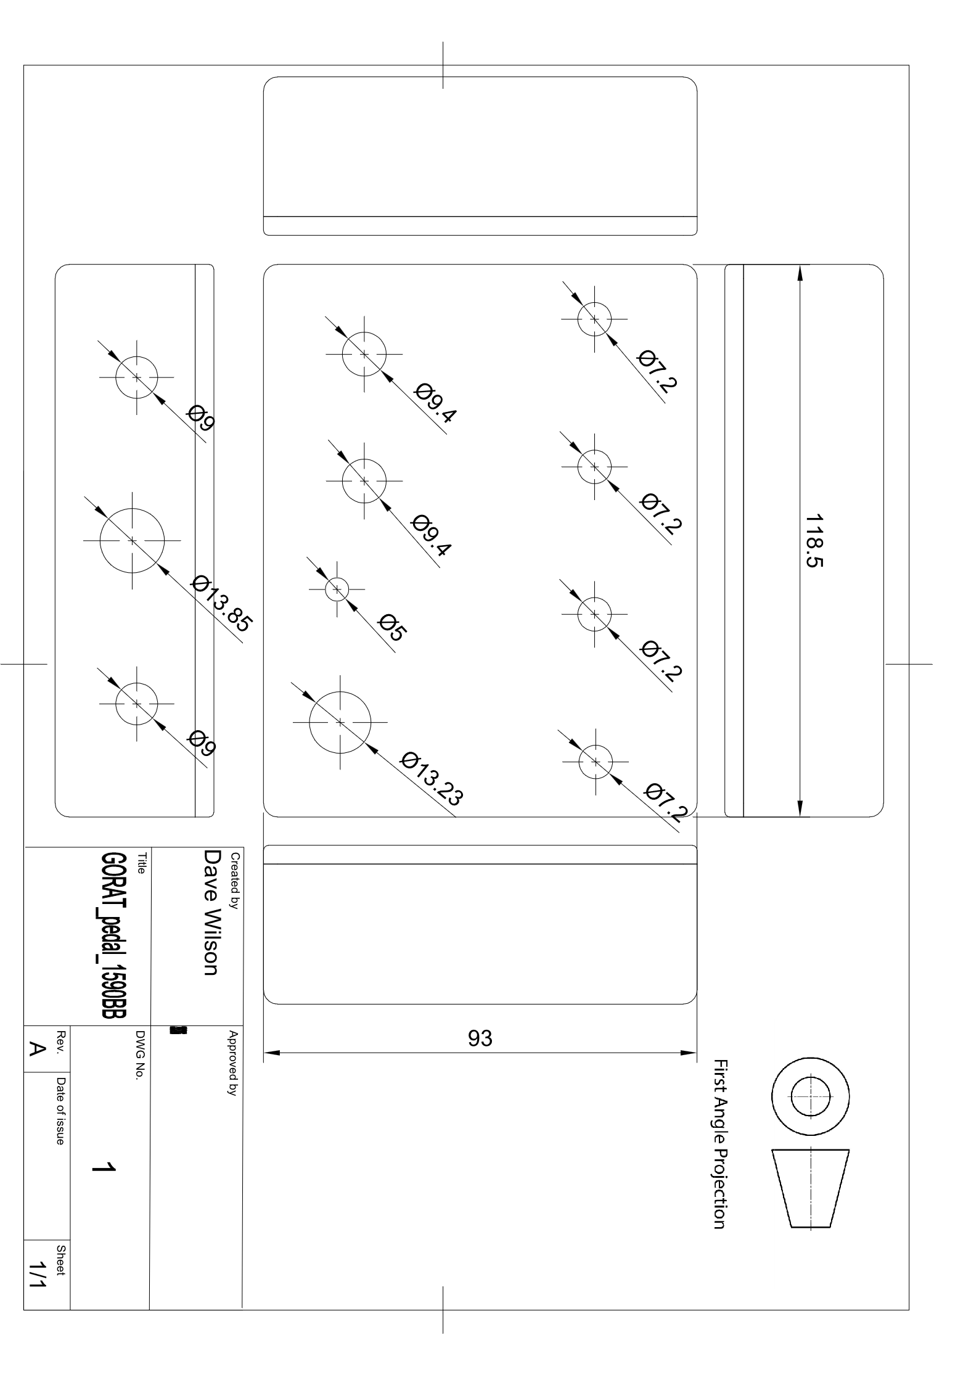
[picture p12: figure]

GoRAT Distortion Pedal – Guide

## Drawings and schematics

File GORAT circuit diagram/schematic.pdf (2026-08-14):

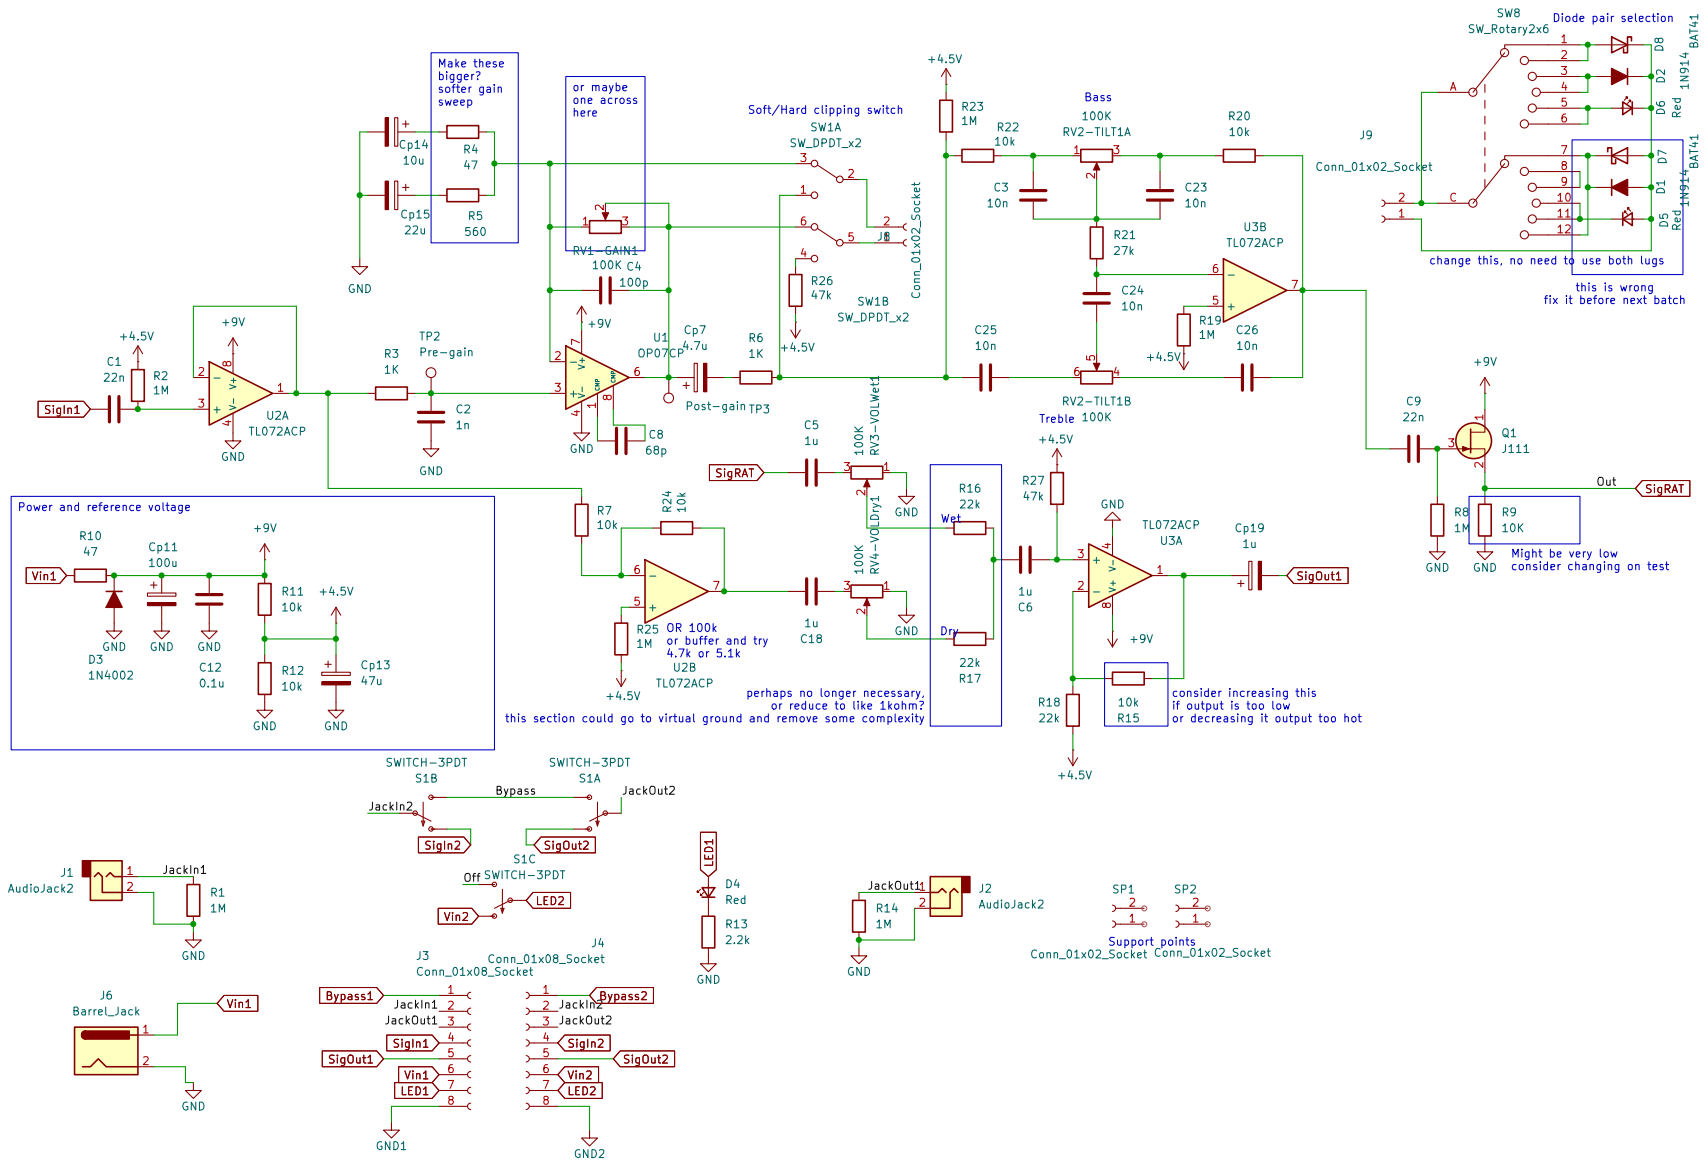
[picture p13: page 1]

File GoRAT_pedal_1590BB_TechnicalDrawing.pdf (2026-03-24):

118.5

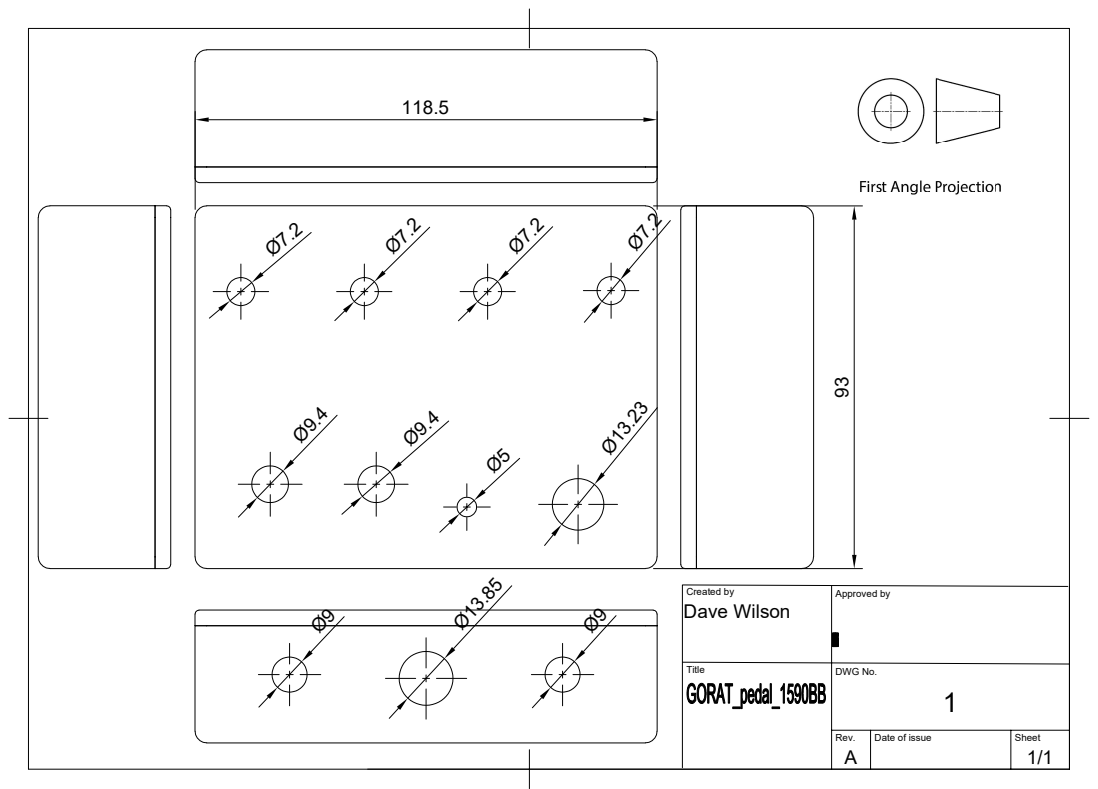
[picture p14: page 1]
Created by; Approved by; Title; DWG No.; Dave Wilson

Rev. A 1/1 | Date of issue | Sheet

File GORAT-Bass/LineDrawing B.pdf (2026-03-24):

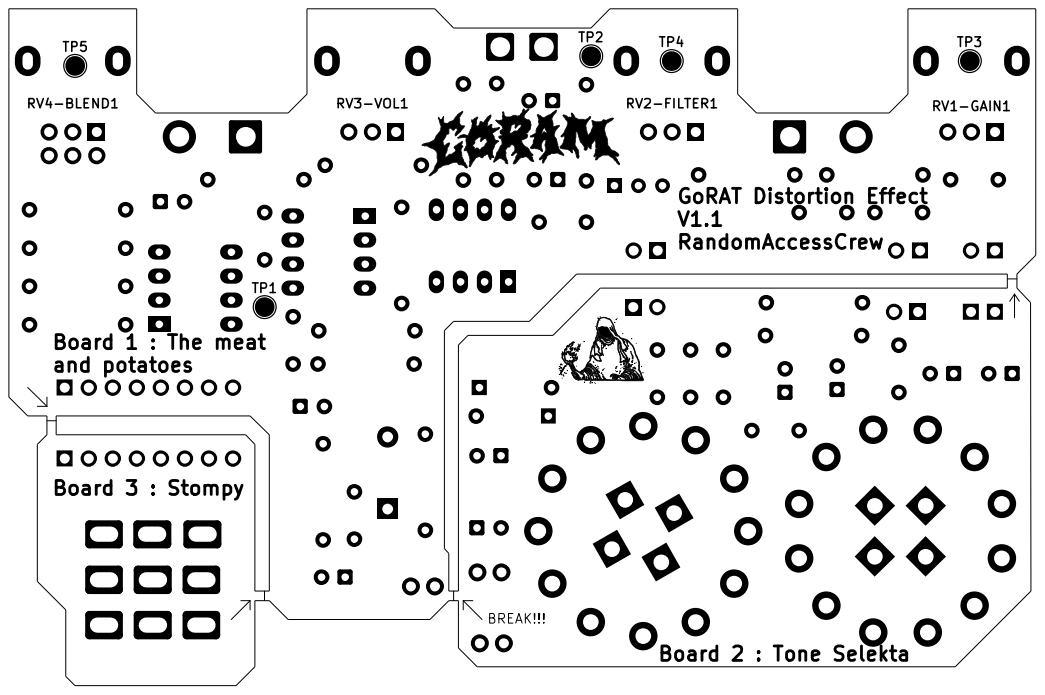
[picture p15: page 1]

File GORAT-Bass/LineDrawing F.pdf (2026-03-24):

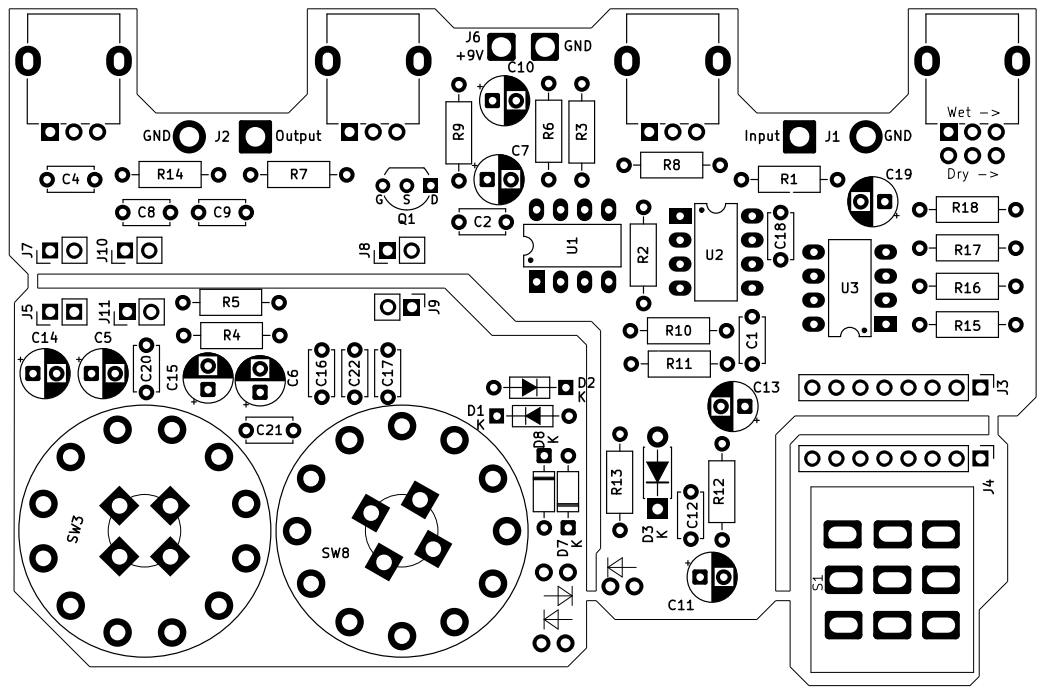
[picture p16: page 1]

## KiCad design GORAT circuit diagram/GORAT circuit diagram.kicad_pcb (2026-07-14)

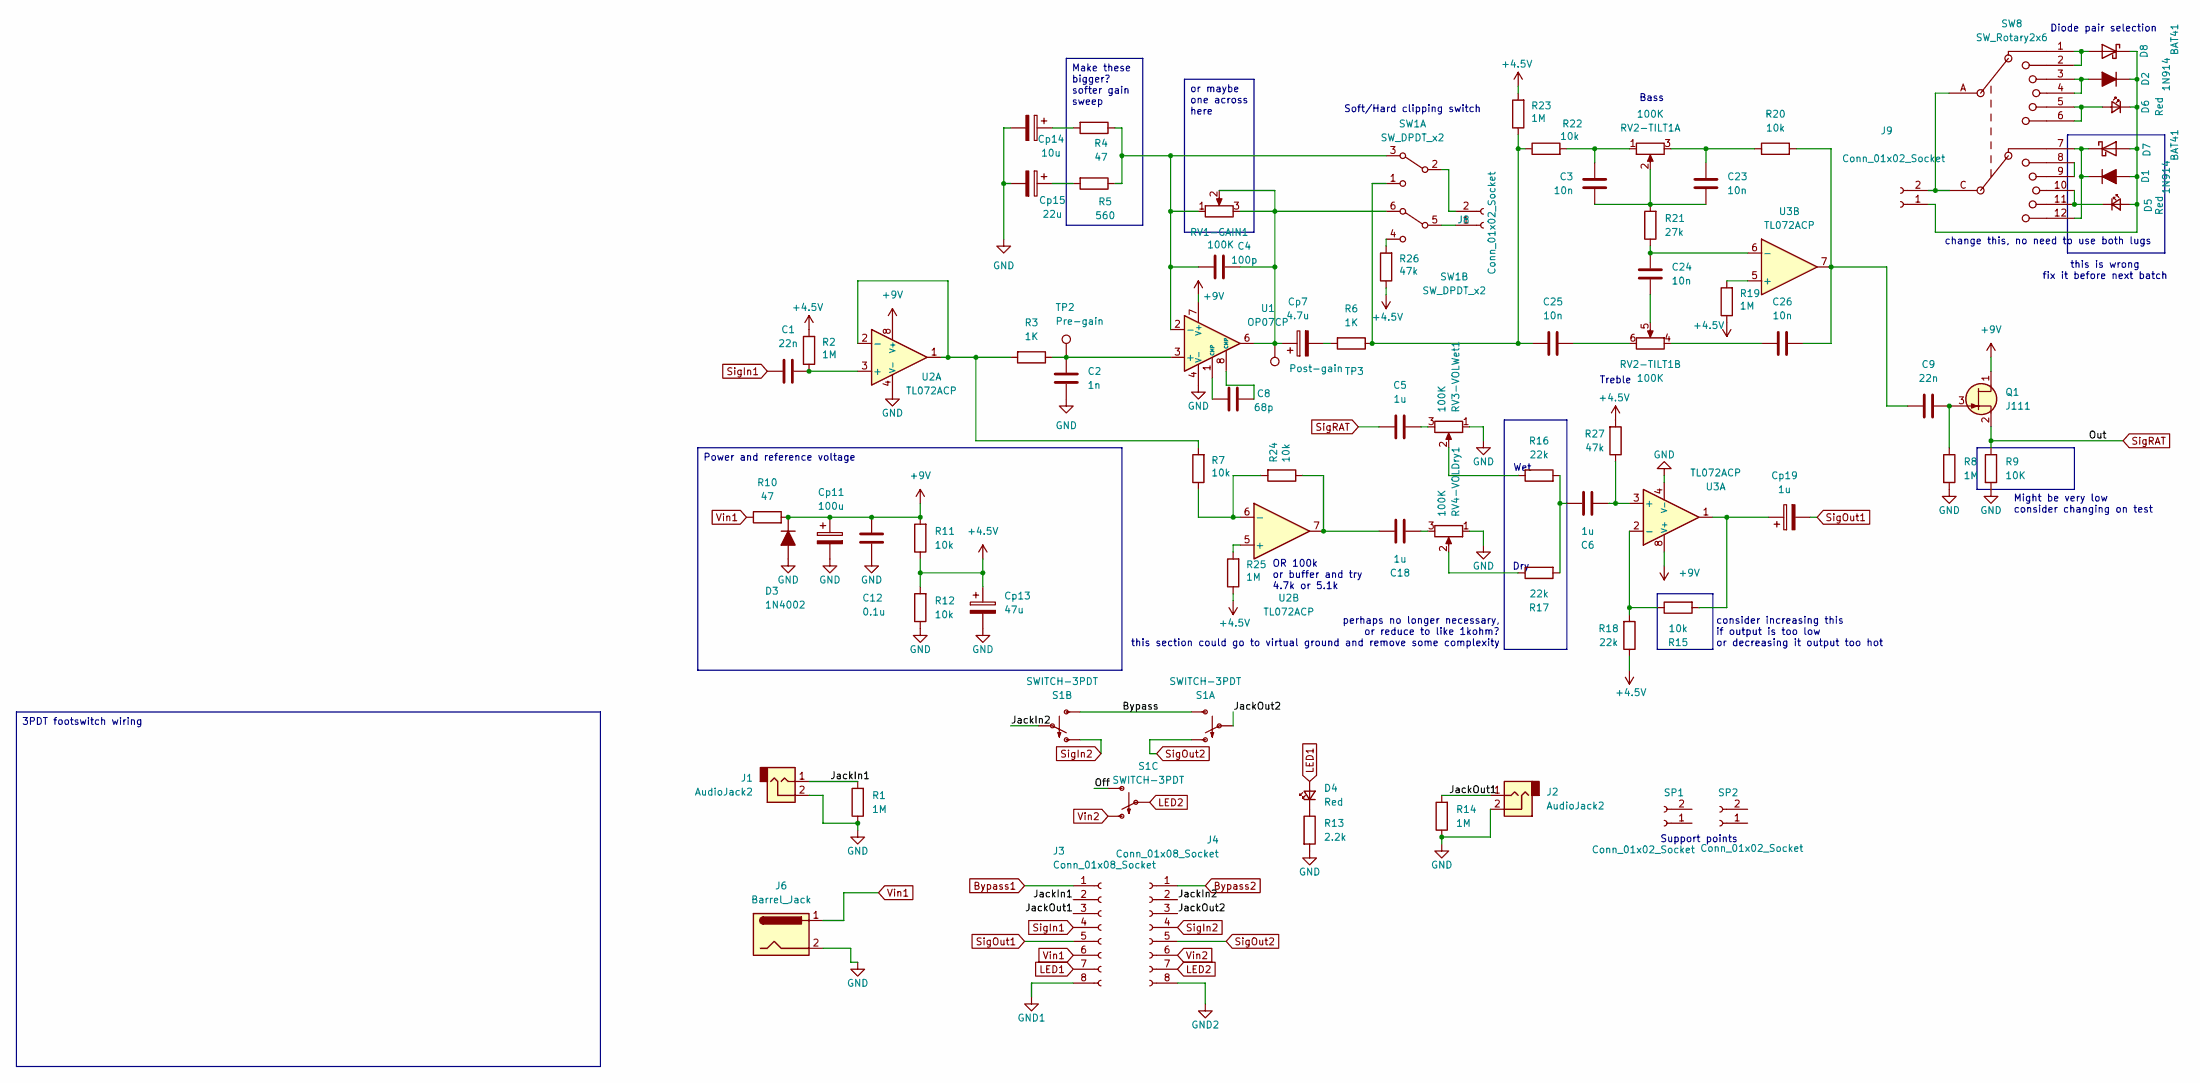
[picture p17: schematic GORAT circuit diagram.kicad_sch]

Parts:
C1, C9: 22n; C_Disc_D4.7mm_W2.5mm_P5.00mm
C2: 1n; C_Disc_D4.7mm_W2.5mm_P5.00mm
C3, C23, C24, C25, C26: 10n; C_Disc_D4.7mm_W2.5mm_P5.00mm
C4: 100p; C_Disc_D4.7mm_W2.5mm_P5.00mm
C5, C6, C18: 1u; C_Disc_D4.7mm_W2.5mm_P5.00mm
C8: 68p; C_Disc_D4.7mm_W2.5mm_P5.00mm
C12: 0.1u; C_Disc_D4.7mm_W2.5mm_P5.00mm
Cp7: 4.7u; CP_Radial_D5.0mm_P2.50mm
Cp11: 100u; CP_Radial_D5.0mm_P2.50mm
Cp13: 47u; CP_Radial_D5.0mm_P2.50mm
Cp14: 10u; CP_Radial_D5.0mm_P2.50mm
Cp15: 22u; CP_Radial_D5.0mm_P2.50mm
Cp19: 1u; CP_Radial_D5.0mm_P2.50mm
D1, D2: 1N914; D_DO-35_SOD27_P7.62mm_Horizontal
D3: 1N4002; D_DO-41_SOD81_P7.62mm_Horizontal
D4: Red; LED_D5.0mm
D5, D6: Red; LED_D3.0mm
D7, D8: BAT41; D_DO-35_SOD27_P7.62mm_Horizontal
J1, J2: AudioJack2; SolderWire-0.75sqmm_1x02_P7mm_D1.25mm_OD3.5mm
J3, J4: Conn_01x08_Socket; PinHeader_1x08_P2.54mm_Vertical
J6: Barrel_Jack; SolderWire-0.5sqmm_1x02_P4.6mm_D0.9mm_OD2.1mm
J8, J9: Conn_01x02_Socket; PinHeader_1x02_P2.54mm_Vertical
Q1: J111; TO-92_Inline_Wide_DSG
R1, R2, R8, R14, R19, R23, R25: 1M; R_Axial_DIN0207_L6.3mm_D2.5mm_P10.16mm_Horizontal
R3, R6: 1K; R_Axial_DIN0207_L6.3mm_D2.5mm_P10.16mm_Horizontal
R4, R10: 47; R_Axial_DIN0207_L6.3mm_D2.5mm_P10.16mm_Horizontal
R5: 560; R_Axial_DIN0207_L6.3mm_D2.5mm_P10.16mm_Horizontal
R7, R11, R12, R15, R20, R22, R24: 10k; R_Axial_DIN0207_L6.3mm_D2.5mm_P10.16mm_Horizontal
R9: 10K; R_Axial_DIN0207_L6.3mm_D2.5mm_P10.16mm_Horizontal
R13: 2.2k; R_Axial_DIN0207_L6.3mm_D2.5mm_P10.16mm_Horizontal
R16, R17, R18: 22k; R_Axial_DIN0207_L6.3mm_D2.5mm_P10.16mm_Horizontal
R21: 27k; R_Axial_DIN0207_L6.3mm_D2.5mm_P10.16mm_Horizontal
R26, R27: 47k; R_Axial_DIN0207_L6.3mm_D2.5mm_P10.16mm_Horizontal
RV1-GAIN1, RV3-VOLWet1, RV4-VOLDry1: 100K; Potentiometer_Alpha_RD901F-40-00D_Single_Vertical
RV2-TILT1: 100K; Potentiometer_Alpha_RD902F-40-00D_Dual_Vertical
S1: SWITCH-3PDT; 3PDT_fixed
SP1, SP2: Conn_01x02_Socket; PinHeader_1x02_P2.54mm_Vertical
SW1: SW_DPDT_x2; DPDT_fixed
SW8: SW_Rotary2x6; RS26
TP2: Pre-gain; TestPoint_Pad_D2.0mm
TP3: Post-gain; TestPoint_Pad_D2.0mm
U1: OP07CP; DIP-8_W7.62mm_LongPads
U2, U3: TL072ACP; DIP-8_W7.62mm_LongPads

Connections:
+4.5V: Cp13.1, R2.2, R11.1, R12.2, R18.1, R19.1, R23.2, R25.1, R26.1, R27.2
+9V: C12.2, Cp11.1, D3.1 (K), Q1.1 (D), R10.2, R11.2, U1.7 (V+), U2.8 (V+), U3.8 (V+)
/Bypass: S1.P$3 (S), S1.P$6 (S)
/JackIn1: J1.1, J3.2, R1.2
/JackIn2: J4.2, S1.P$5
/JackOut1: J2.1, J3.3, R14.2
/JackOut2: J4.3, S1.P$2
/Off: S1.P$9 (S)
Bypass1: J3.1
Bypass2: J4.1
GND: C2.1, C12.1, Cp11.2, Cp13.2, Cp14.2, Cp15.2, D3.2 (A), J1.2, J2.2, J6.2, R1.1, R8.2, R9.2, R12.1, R13.2, R14.1, RV3-VOLWet1.1, RV4-VOLDry1.1, U1.4 (V-), U2.4 (V-), U3.4 (V-)
GND1: J3.8
GND2: J4.8
LED1: D4.2 (A), J3.7
LED2: J4.7, S1.P$8
unnamed: C3.2, R22.2, RV2-TILT1.1
unnamed: C5.2, RV3-VOLWet1.3
unnamed: C6.1, R16.2, R17.2
unnamed: C8.1, U1.1 (CMP)
unnamed: C8.2, U1.8 (CMP)
unnamed: C18.1, R24.1, U2.7
unnamed: C18.2, RV4-VOLDry1.3
unnamed: C3.1, C23.1, R21.2, RV2-TILT1.2
unnamed: C23.2, R20.1, RV2-TILT1.3
unnamed: C24.1, RV2-TILT1.5
unnamed: C25.1, RV2-TILT1.6
unnamed: C9.2, C26.1, R20.2, U3.7
unnamed: C26.2, RV2-TILT1.4
unnamed: Cp7.2, R6.2
unnamed: Cp14.1, R4.2
unnamed: Cp15.1, R5.2
unnamed: Cp19.1, R15.2, U3.1
unnamed: D1.2 (A), D2.1 (K), D5.2 (A), D6.1 (K), D7.2 (A), D8.1 (K), J9.1
unnamed: D1.1 (K), D7.1 (K), SW8.7, SW8.12
unnamed: D2.2 (A), SW8.3, SW8.4
unnamed: D4.1 (K), R13.1
unnamed: D5.1 (K), SW8.10, SW8.11
unnamed: D6.2 (A), SW8.5, SW8.6
unnamed: D8.2 (A), SW8.1, SW8.2
unnamed: J8.1, SW1.5 (B)
unnamed: J8.2, SW1.2 (B)
unnamed: J9.2, SW8.A, SW8.C
unnamed: C9.1, Q1.3 (G), R8.1
unnamed: R16.1, RV3-VOLWet1.2
unnamed: R17.1, RV4-VOLDry1.2
unnamed: C25.2, R6.1, R22.1, R23.1, SW1.1 (A)
unnamed: C4.2, R4.1, R5.1, RV1-GAIN1.1, SW1.3 (C), U1.2 (-)
unnamed: R26.2, SW1.4 (A)
unnamed: C4.1, Cp7.1, RV1-GAIN1.2, RV1-GAIN1.3, SW1.6 (C), TP3.1, U1.6
unnamed: SW8.8, SW8.9
unnamed: C2.2, R3.1, TP2.1, U1.3 (+)
unnamed: C1.2, R2.1, U2.3 (+)
unnamed: R3.2, R7.2, U2.1, U2.2 (-)
unnamed: R25.2, U2.5 (+)
unnamed: R7.1, R24.2, U2.6 (-)
unnamed: C6.2, R27.1, U3.3 (+)
unnamed: R15.1, R18.2, U3.2 (-)
unnamed: R19.2, U3.5 (+)
unnamed: C24.2, R21.1, U3.6 (-)
SigIn1: C1.1, J3.4
SigIn2: J4.4, S1.P$4 (O)
SigOut1: Cp19.2, J3.5
SigOut2: J4.5, S1.P$1 (O)
SigRAT: C5.1, Q1.2 (S), R9.1
Vin1: J3.6, J6.1, R10.1
Vin2: J4.6, S1.P$7 (O)

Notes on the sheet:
Wet
OR 100k or buffer and try 4.7k or 5.1k
Might be very low consider changing on test
Soft/Hard clipping switch
consider increasing this if output is too low or decreasing it output too hot
change this, no need to use both lugs
Treble
Support points
Bass
perhaps no longer necessary, or reduce to like 1kohm? this section could go to virtual ground and remove some complexity
Diode pair selection
Dry
this is wrong fix it before next batch
or maybe one across here
Make these bigger? softer gain sweep
3PDT footswitch wiring
Power and reference voltage

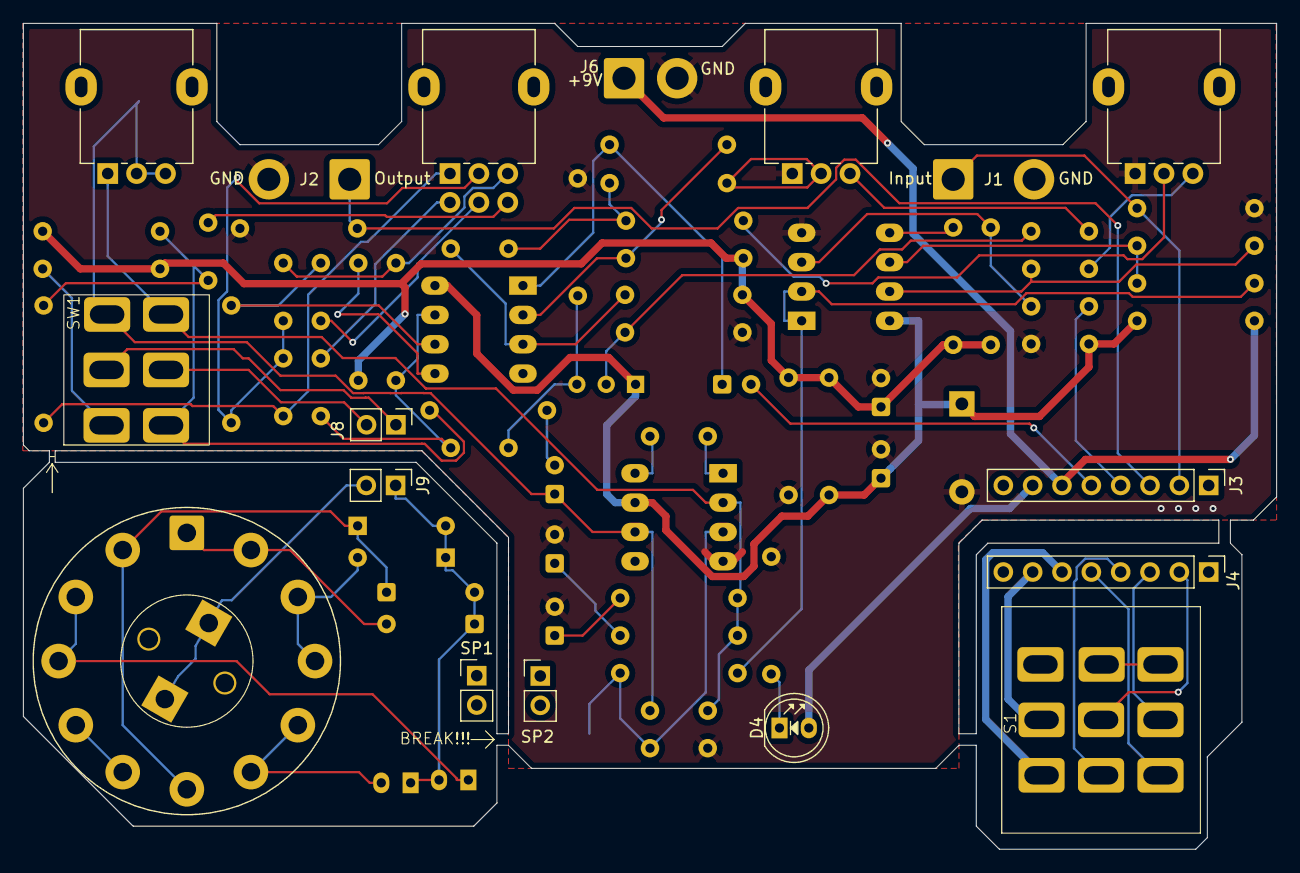
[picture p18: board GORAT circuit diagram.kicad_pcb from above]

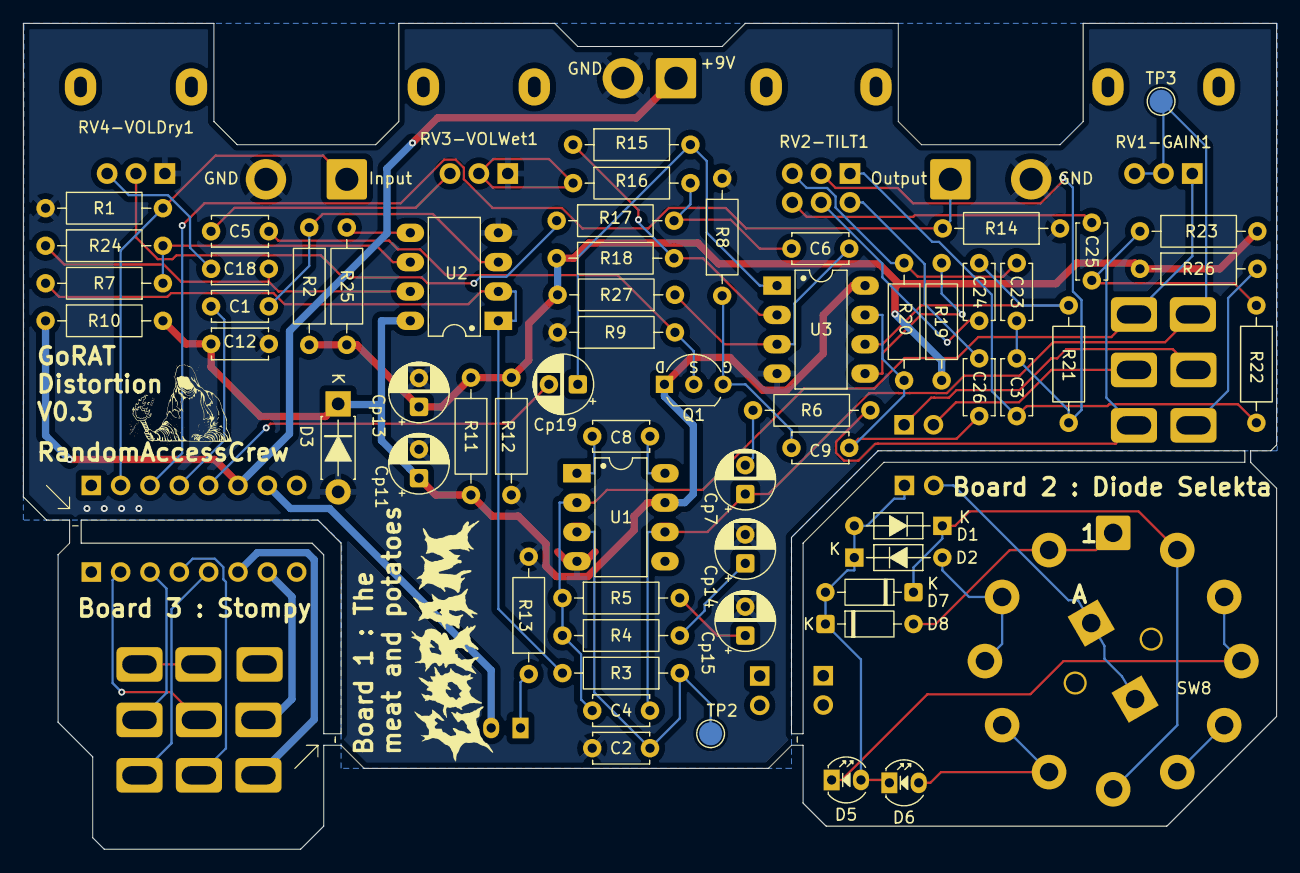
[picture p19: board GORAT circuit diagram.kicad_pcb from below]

Board: 2 copper layers, 108.5 x 71.5 mm, 77 parts (60 on the bottom side), 61 nets.

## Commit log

2026-02-17 Add KiCad project files for GORAT circuit
    Initial import of the GORAT guitar pedal KiCad project. Adds schematic (.kicad_sch), PCB (.kicad_pcb), project file (.kicad_pro), project preferences (.kicad_prl), fp-info-cache, autosave/lock file a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
    [GORAT circuit diagram.kicad_pcb, GORAT circuit diagram.kicad_sch]
2026-02-19 Add ngspice support and schematic backups
    Enable ngspice in the KiCad project and update the schematic for simulation: add ngspice config and workbook in .kicad_pro; replace/extend power symbols with Simulation_SPICE VDC/VSIN symbols and simulation properties (Sim.Type, Sim.Device, Sim.Params); add .param and .ac directives and a workbook (.wbk) file. Also remove an autosave and schematic lock file, add multiple schematic backup .zip files and a .kicad_sch-bak. Numerous junctions, wires and UUIDs updated to reflect schematic edits.
2026-03-02 Update KiCad PCB and add backups
    Replace GORAT circuit diagram.kicad_pcb with the full PCB data (expanded footprints, nets, layers and layout). Update related project files (GORAT circuit diagram.kicad_pro, .kicad_sch and fp-info-cache). Add multiple timestamped backup ZIPs under GORAT circuit diagram/GORAT circuit diagram-backups (dates 2026-02-27 and 2026-03-02).
    [GORAT circuit diagram.kicad_pcb, GORAT circuit diagram.kicad_sch]
2026-03-09 almost done
    [GORAT circuit diagram.kicad_pcb, GORAT circuit diagram.kicad_sch]
2026-03-11 close to done
    [GORAT circuit diagram.kicad_pcb, GORAT circuit diagram.kicad_sch, Underside-layout.dxf]
2026-03-11 Update KiCad PCB, add backups and artwork
    Modify GORAT circuit diagram.kicad_pcb: reorder/renumber nets, adjust several pad/net assignments and component positions, and add numerous F.Fab properties (Availability, Check_prices, Description_1, MF, MP, Package, Price, Sim.Type, SnapEDA_Link) for multiple footprints. Remove several old backup ZIPs and add new timestamped backup ZIPs. Add new project assets: GoRAT.csv and artwork/renders (goram-mirror.svg, goram.png, goram.svg, underside.svg). These changes appear to be from a PCB/footprint update and exporting backup/artwork files.
    [GORAT circuit diagram.kicad_pcb, GORAT circuit diagram.kicad_sch, GoRAT.csv]
2026-03-12 Enhance README with diode options and future features
    Added future features section and expanded diode selector details.
2026-03-12 Add Colour LED display feature to README
    Added a section about the Colour LED display feature.
2026-03-18 Update disc capacitor footprints and BOM
    Replace THT disc capacitor footprints with smaller C_Disc_D4.7mm_W2.5mm variants across schematic and PCB (updated 3D model paths, silk/text positions, rotations and UUIDs). Update project metadata: change active board layer in .kicad_prl, set BOM export filename in .kicad_pro, and add generated BOM CSV/XLSX. Add KiCad backup archives and remove autosave/.lck temporary files to keep the repo clean.
    [GORAT circuit diagram.kicad_pcb, GORAT circuit diagram.kicad_sch, GoRAT (version 1).csv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]
2026-03-20 BOM work
    [GORAT circuit diagram-B_Cu.gbl, GORAT circuit diagram-B_Cu.gbr, GORAT circuit diagram-B_Mask.gbr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]
2026-03-24 Add PCB delivery update to README
    Added update section with PCB delivery details and images.
2026-03-24 Fix formatting and update PCB design details
    Corrected formatting for the update section and added details about the PCB design.
2026-03-24 Create PCBv1.1 delivery.jpg
2026-03-24 Remove PCB delivery image from README
    Removed the PCB delivery image from the README.
2026-03-24 Add PCB delivery image to README
    Added an image of the PCB delivery to the README.
2026-03-24 Update KiCad PCB, add build guide & backups
    Apply multiple updates to the GoRAT project: modify the KiCad PCB (footprint/pad geometry, silkscreen labels, routing segments and UUIDs), and update accompanying KiCad project files and the GoRAT sp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
    [GoRAT (version 1).xlsx]
2026-03-25 begun bass version
    [GORAT circuit diagram-B_Cu.gbl, GORAT circuit diagram-B_Cu.gbr, GORAT circuit diagram-B_Mask.gbr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]
2026-03-26 Fixed disconnection issue
    [GORAT circuit diagram.kicad_sch]
2026-03-31 fixed issues
    [GORAT circuit diagram 1.2.kicad_sch, GORAT circuit diagram.kicad_sch]
2026-04-01 Update GORAT KiCad PCB, schematics & backups
    Modify KiCad project files and update backup archives. Changes include:
    - Updated Build_Guide.docx (binary change).
    - Removed several older GORAT backup ZIPs and added new backups dated 2026-04-01.
    - Extensive edits to GORAT circuit diagram.kicad_pcb: net renumbering/reassignments, footprint position adjustments, pad/net fixes, updated pad/net mappings, many UUID/fp_line/fp_poly/attribute adjustments, and a footprint rename (3PDT -> 3PDT_fixed).
    - Minor updates to GORAT circuit diagram.kicad_prl, .kicad_sch and fp-info-cache.
    These changes appear to realign component placements and correct net assignments in the PCB while refreshing project backup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
    [GORAT circuit diagram.kicad_sch]
2026-04-01 Update KiCad schematic positions and prefs
    Enable additional selection filters in GORAT circuit diagram.kicad_prl (dimensions, footprints, graphics, keepouts, otherItems, pads, text, vias, zones) to improve editing. Adjust many coordinates in GORAT circuit diagram.kicad_sch (junctions, wires, global labels and symbol/component positions) to reposition and tidy the schematic. Replace an older backup zip with a new timestamped backup.
    [GORAT circuit diagram.kicad_sch]
2026-04-02 Update KiCad schematic and PCB to v1.3
    Add new KiCad schematic 'GORAT circuit diagram 1.3.kicad_sch' and v1.3 PCB/project files; modify existing GORAT schematic, PCB (.kicad_pcb) and project library (.kicad_prl). Add multiple backup ZIP a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
    [GORAT circuit diagram 1.3.kicad_sch, GORAT circuit diagram.kicad_sch]
2026-04-06 Adjust KiCad schematic junctions and wires
    Rearranged junctions and wires in GORAT circuit diagram.kicad_sch to correct routing and updated related UUIDs; also moved several diode symbol positions (D1, D2, D7, D8). Added two new schematic backup ZIPs (2026-04-06) and removed an older backup (2026-03-20). Deleted temporary .lck lock files generated by KiCad.
    [GORAT circuit diagram.kicad_sch]
2026-04-10 Update Build_Guide and add GORAT backup zip
    Update Build_Guide.docx (documentation changes) and add a new backup ZIP for the GORAT circuit diagram: GORAT circuit diagram-2026-04-04_053106.zip under the backups folder.
    [GORAT circuit diagram.kicad_pcb, GORAT circuit diagram.kicad_sch, GoRATv0.2.step]
2026-04-13 potentially fixed volume mixer
    [GORAT circuit diagram.kicad_pcb, GORAT circuit diagram.kicad_sch]
2026-04-13 Schematic: add +5V, C6, R27; adjust wires
    Added a +5V power symbol, C6 (1u) and R27 (47k); adjusted component positions, junctions and wire routing to match the new connections. Updated a resistor value from 100k to 10k and corrected several UUIDs for wires/junctions. Also updated autosave path and KiCad .lck metadata and renamed a few backup zip files. These changes update schematic connectivity and component placement.
    [GORAT circuit diagram.kicad_sch]
2026-04-14 update board and layout
    [GORAT circuit diagram.kicad_pcb, GORAT circuit diagram.kicad_sch, GORAT_pedal_v0.2_1590BB Drawing v1 Sheet1.dxf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]
2026-04-14 Update KiCad files: remap nets and rename caps
    Synchronise PCB and schematic: remap many net indices across GORAT circuit diagram (.kicad_pcb, .kicad_sch, .kicad_prl, .kicad_pro) to match the schematic, and rename several capacitor references (e.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
    [GORAT circuit diagram.kicad_pcb, GORAT circuit diagram.kicad_sch, GoRAT (version 1).xlsx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]
2026-04-14 Add net color definitions and remove PCB lockfile
    Set net color mappings in the KiCad project file for +4.5V and +9V nets to make them visually distinct. Also remove the transient PCB lock file (~GORAT circuit diagram.kicad_pcb.lck) that contained h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
2026-04-15 Add GoRAT schematic files; update SVG layout
    Add GoRATv0.2.xlsx and a circuit-diagram backup zip. Modify GoRAT_pedal_1590BB_TechnicalDrawing.svg to change canvas size/orientation (viewBox and width/height), update Inkscape document metadata (zo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
    [GoRATv0.2.xlsx]
2026-04-24 V0.2 finished
    [GORAT circuit diagram-B_Cu.gbl, GORAT circuit diagram-B_Mask.gbs, GORAT circuit diagram-B_Paste.gbp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]
2026-07-14 Fixed pop by enabling always-on
    [GORAT circuit diagram.kicad_pcb, GORAT circuit diagram.kicad_sch]
2026-08-14 Create GORAT v2.0 schematic project
    Initialize new KiCAD project structure for GORAT v2.0 with complete schematic files (kicad_sch, kicad_pro, kicad_prl, kicad_pcb) and backups. Add schematic PDF export. Move project lock file and clea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
    [GORAT v2.0.kicad_pcb, GORAT v2.0.kicad_sch]
